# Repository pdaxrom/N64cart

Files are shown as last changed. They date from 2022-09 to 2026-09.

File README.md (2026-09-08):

# N64cart - N64 flash cartridge

* [Intro](#intro)
* [Concept](#concept)
  * [Project files](#project-files)
  * [Features](#features)
  * [Memory mapping](#memory-mapping)
* [PCB](#pcb)
  * [Order notes](#order-notes)
  * [Assembly notes](#assembly-notes)
* [Build firmware](#build-firmware)
* [Build ROM Manager](#build-rom-manager)
* [Cartridge utility](#cartridge-utility)
  * [Build](#build)
  * [How to use](#how-to-use)
  * [Remote access to the cartridge](#remote-access-to-the-cartridge)
* [ROMFS Manager](#romfs-manager)
* [Total cartridge cost (32 MB version)](#total-cartridge-cost-32-mb-version)
* [Photos of version 2](#photos-of-version-2)
* [Bill of materials for version 3](#bill-of-materials-for-version-3)
* [Photos of version 3](#photos-of-version-3)
* [Remote access from an SGI Indy](#remote-access-from-an-sgi-indy)

## Intro

N64cart is an inexpensive N64 flash cartridge you can build at home. The hardware and firmware started as a fork of Konrad Beckmann's [PicoCart64](https://github.com/kbeckmann/PicoCart64), which uses a Raspberry Pi Pico as a memory controller.

The N64 cartridge connector footprint for Eagle CAD comes from [SummerCart64](https://github.com/Polprzewodnikowy/SummerCollection).

The N64 ROM boot code is derived from [N64FlashcartMenu](https://github.com/Polprzewodnikowy/N64FlashcartMenu) and [N64 DreamOS ROM](https://github.com/khill25/Dreamdrive64/tree/main/sw/n64).

## Concept

To keep the cartridge simple and inexpensive, I used one SPI flash chip and one RP2040. Konrad's design used multiplexed PSRAM chips and two RP2040s. Flash chips rated for more than 100,000 erase/program cycles should last for many years of home use.

The RP2040's XIP interface directly addresses up to 16 MB of flash. The early design used the Extended Address (EA) register to switch between 16 MB banks on larger chips. This was slow: each bank switch required disabling XIP, switching to SPI mode to update the register, and then re-enabling XIP. N64cart now uses QSPI with 32-bit addressing, without XIP, to avoid bank switching.

The [romfs](fw/romfs) filesystem maps the sectors of stored files into a contiguous address space that the N64 accesses through the PI bus. Maximum flash capacity depends on the board version: 64 MB for version 2 with a SOIC-8 or 8 × 6 mm WSON-8 package, and 128 MB for version 3 with a SOIC-16 package.

### Project files

#### Cartridge board version 2 (SOIC-8 / WSON-8, 8 × 6 mm; 64 MB maximum)

[Schematic (PDF)](hw/n64cart-v2-soic-8.pdf)

[Schematic (Eagle CAD)](hw/n64cart-v2-soic-8.sch)

[PCB (Eagle CAD)](hw/n64cart-v2-soic-8.brd)

[Gerber files](hw/n64cart-v2-soic-8_2024-08-11.zip)

#### Cartridge board version 3 (SOIC-16; 128 MB maximum)

[Schematic (PDF)](hw/n64cart-v3-soic-16.pdf)

[Schematic (Eagle CAD)](hw/n64cart-v3-soic-16.sch)

[PCB (Eagle CAD)](hw/n64cart-v3-soic-16.brd)

[Gerber files](hw/n64cart-v3-soic-16_2024-08-11.zip)

### Features

- One LED controlled by the N64, with WS2812 RGB support on PCB version 3 (not available on PicoCart64-lite)
- A UART port accessible from the N64 (not available on PicoCart64-lite)
- USB passthrough to the N64
- Emulation of 4/16 Kbit EEPROM
- Emulation of 256 Kbit / 1 Mbit SRAM
- Emulation of 1 Mbit FlashRAM (29L1100)
- A USB utility for accessing files on the cartridge's flash chip

### Memory mapping

#### Registers

Register|Address|Mode
--------|-------|----
UART_CTRL|0x1fd01000|R-
UART_RXTX|0x1fd01004|RW
LED_CTRL|0x1fd01008|-W
SYS_CTRL|0x1fd0100c|RW
SSI_SR|0x1fd01010|RW
SSI_DR0|0x1fd01014|RW
FW_SIZE|0x1fd01018|R-

#### UART_CTRL bits

Function|Bit mask|Mode
--------|--------|----
UART_RX_AVAIL|0x01|R-
UART_TX_FREE|0x02|R-

#### UART_RXTX bits

Function|Bit mask|Mode
--------|--------|----
DATA|0xFF|RW

#### LED control bits

Function|Bit mask|Mode|Note
--------|--------|----|---
LED_ONOFF|0x01|-W|PCB v2 or PCB v3 without WS2812
LED_RGB|0x00ffffff|-W|PCB v3 only

#### SYS_CTRL bits

Function|Bit mask|Mode
--------|--------|----
EEPROM_16KBIT|0x1000|RW
FRAM_MODE|0x200|RW
SRAM_UNLOCK|0x100|RW
FLASH_MODE_QUAD|0x10|RW
FLASH_CS_HIGH|0x01|RW

#### SSI_SR bits

Function|Bit mask|Mode
--------|--------|----
SSI_SR_TFNF_BITS|0x01|R-
SSI_SR_RFNE_BITS|0x02|R-

#### SSI_DR0 bits

Function|Bit mask|Mode
--------|--------|----
DATA|0xff|RW

## PCB

### Order notes

Use a PCB thickness of 1.2 mm.

A stencil makes it easier to apply solder paste, but adds to the order cost.

### Assembly notes

After soldering the processor and flash chip, thoroughly remove flux residue from the board. Residue can cause unstable memory operation or prevent the cartridge from working.

#### PCB version 2

Populate either D2 or Q1, but not both.

Leave R1 and R6 unpopulated.

#### PCB version 3

If LED3 is populated, leave R1 and D2 unpopulated.

## Build firmware

Install the Pico SDK before building the firmware.

The default configuration is `BOARD=v3` and `REGION=ntsc`. Pass one of these options to CMake to select a different board:

- `-DBOARD=v2`: cartridge version 2 with 32/64 MB flash.
- `-DBOARD=pico`: a generic Pico cartridge with up to 16 MB of flash, without the `SI_DAT`, `SI_CLK`, `NMI`, and `INT` signals.
- `-DBOARD=pico-lite`: a PicoCart64-lite cartridge with up to 16 MB of flash, with the `SI_DAT`, `SI_CLK`, `NMI`, and `INT` signals.

Select the firmware region according to the console:

| Console | CMake option | ROM Manager video mode |
|---|---|---|
| NTSC | `-DREGION=ntsc` (default) | NTSC |
| PAL | `-DREGION=pal` | PAL |
| PAL-M / MPAL (Brazil) | `-DREGION=ntsc` (default) | MPAL |

`REGION` selects the cartridge's CIC security protocol. PAL-M consoles use the same protocol as NTSC consoles, so choose the NTSC firmware build for PAL-M too. ROM Manager gets the console's TV type from libdragon and selects the video mode automatically. No separate PAL-M build is needed, though it still needs testing on a real PAL-M console.

From the repository root, build the default configuration:

```sh
cd fw
mkdir -p build
cd build
cmake ..
make -j
```

For example, use `cmake .. -DBOARD=v2 -DREGION=pal` to build for a version 2 cartridge and a PAL console.

Hold the cartridge's bootloader button while connecting it via USB, then copy `fw/build/n64cart.uf2` to the `RPI-RP2` drive.

## Build ROM Manager

Install an N64 toolchain with [libdragon](https://github.com/DragonMinded/libdragon) built from the `opengl` branch.

Pass `BOARD=pico` to `make` for a generic Pico cartridge, or `BOARD=pico-lite` for a PicoCart64-lite cartridge. Both configurations support flash chips of up to 16 MB. No `REGION` option is needed: video mode selection is automatic for NTSC, PAL, and PAL-M consoles.

From the repository root:

```sh
cd rom
make
```

## Cartridge utility

The utility formats cartridge memory and reads and writes files. Use it to upload ROMs or change the background image.

### Build

For Linux and macOS, install the libusb development files. From the repository root:

```sh
cd utils
make
```

To build for Windows, install the MinGW toolchain. From the repository root:

```sh
cd utils
make SYSTEM=Windows
```

### How to use

Run the following commands from the `utils` directory. Before using a new cartridge, format it and upload ROM Manager:

```sh
./usb-romfs format
./usb-romfs push ../rom/n64cart-manager.z64
```

Upload a ROM, for example:

```sh
./usb-romfs push game.z64
```

To change the background image:

```sh
./usb-romfs push picture.jpg background.jpg
```

Available commands (angle brackets indicate placeholders; square brackets indicate optional arguments):

```text
./usb-romfs help
./usb-romfs bootloader
./usb-romfs reboot
./usb-romfs format
./usb-romfs list [-h] [path]
./usb-romfs delete <remote path>
./usb-romfs mkdir <remote path>
./usb-romfs rmdir <remote path>
./usb-romfs rename <source> <destination> [--create-dirs]
./usb-romfs push [--fix-rom] [--fix-pi-bus-speed[=12..FF]] <local filename> [<remote path>]
./usb-romfs pull <remote path> [<local filename>]
./usb-romfs free
```

### Remote access to the cartridge

If your computer cannot connect to the cartridge directly, you can access it through a USB-connected proxy computer. This is useful for older systems without USB, such as an SGI Indy. Build the remote-access utilities from the `utils` directory:

```sh
make remote
```

If the client and proxy use different architectures or operating systems, cross-compile `remote-romfs` for the client by specifying the compiler:

```sh
make CC="mips-sgi-irix6o32-gcc" remote-romfs
```

Copy `remote-romfs` to the client. On the proxy computer, connect the cartridge via USB and start the proxy:

```sh
./proxy-romfs
```

On the client, `remote-romfs` takes the same commands as `usb-romfs`. Add the proxy's IP address before the command:

```text
./remote-romfs <proxy IP address> <command ...>
```

[Photos of remote access from an SGI Indy](#remote-access-from-an-sgi-indy)

## ROMFS Manager

[ROMFS Manager](utils/romfs-gui) is a desktop application built with Qt. You can use it to browse, upload, and download files on N64cart over USB or through a remote proxy.

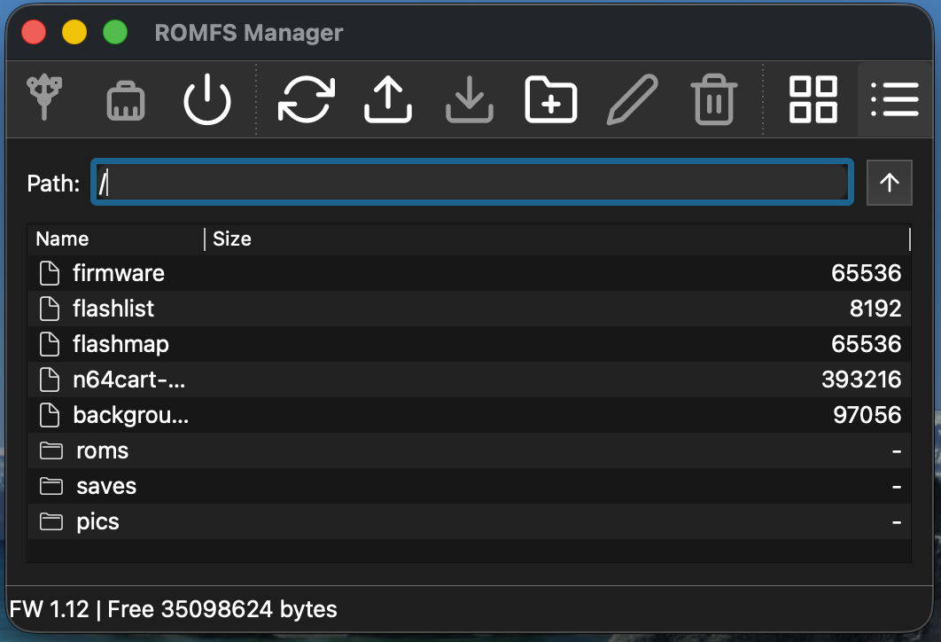
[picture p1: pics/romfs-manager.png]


## Total cartridge cost (32 MB version)

The following is an example cost breakdown for the 32 MB version. Shipping can
cost more than the components when ordering only one or two of each item.
Larger orders may qualify for free shipping.

Seller|Delivery cost|Components
------|-------------|---
[Chicago Electronic Distributors](https://chicagodist.com/)|$6-$11|RP2040
[Arrow](https://www.arrow.com/)|Free for orders > $50|SPI flash, resistors, capacitors, etc.
[JLCPCB](https://jlcpcb.com/)|$22.40|PCB

In this example, five PCBs cost $2 for the first PCB design in an order, or $4 for each additional design.

The most expensive components:

Component|Quantity|Price
---------|---|-----
RP2040|1|$1
W25Q256JVEIQ|1|$4.24
ABLS-12.000MHZ-B4-T|1|$0.26
UJ2-MIBH-G-SMT-TR|1|$0.45
LDI1117-3.3U|1|$0.34
BAT60AE6327HTSA1|2|$0.93

The remaining components (LEDs, resistors, and capacitors) came from existing stock and cost less than $1 in total.

The estimated total cost of the PCB and components is approximately $9, excluding shipping.

## Photos of version 2

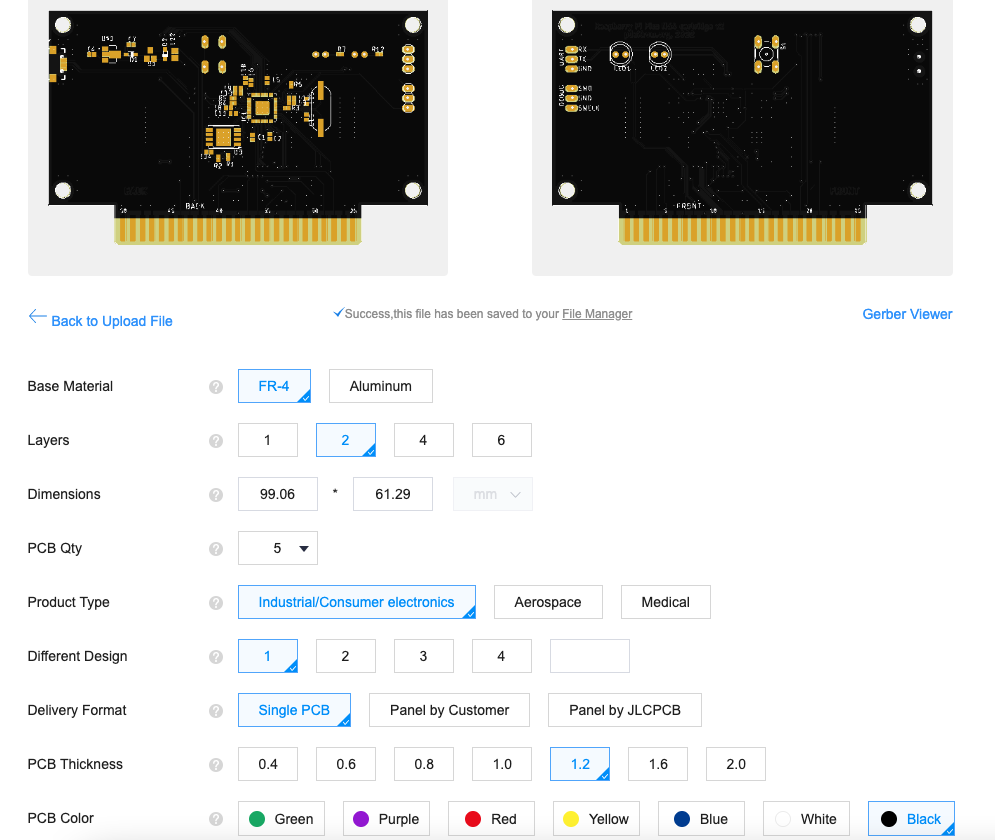
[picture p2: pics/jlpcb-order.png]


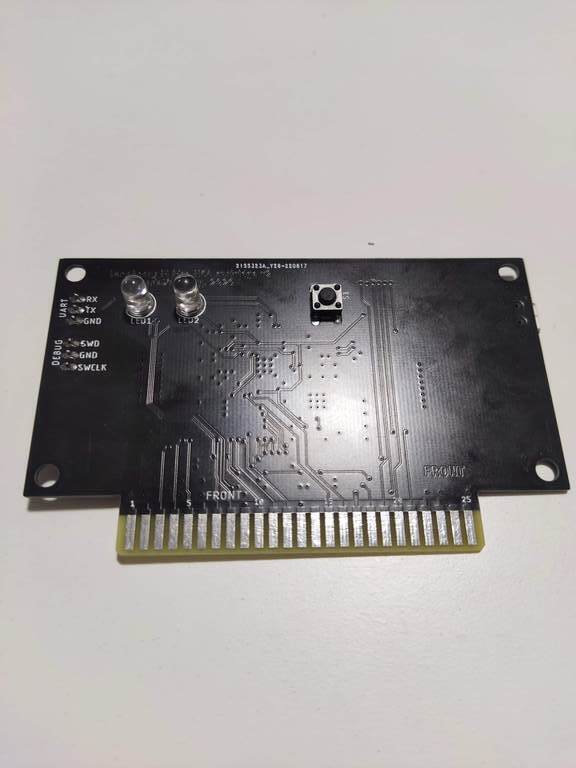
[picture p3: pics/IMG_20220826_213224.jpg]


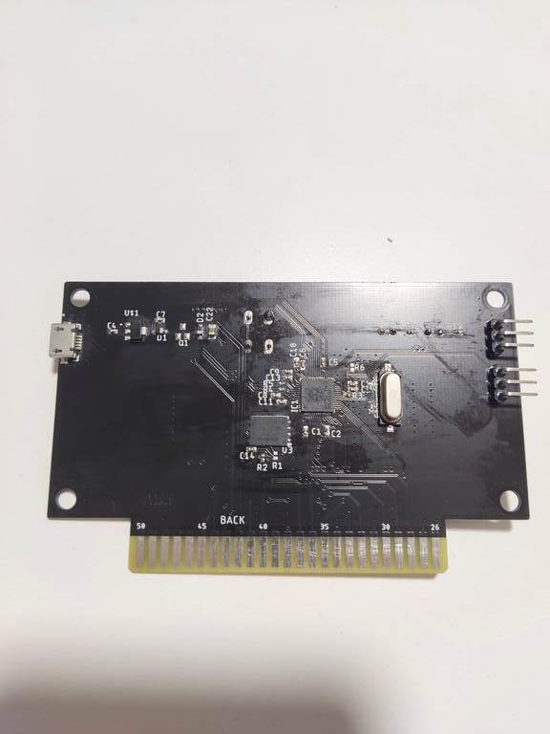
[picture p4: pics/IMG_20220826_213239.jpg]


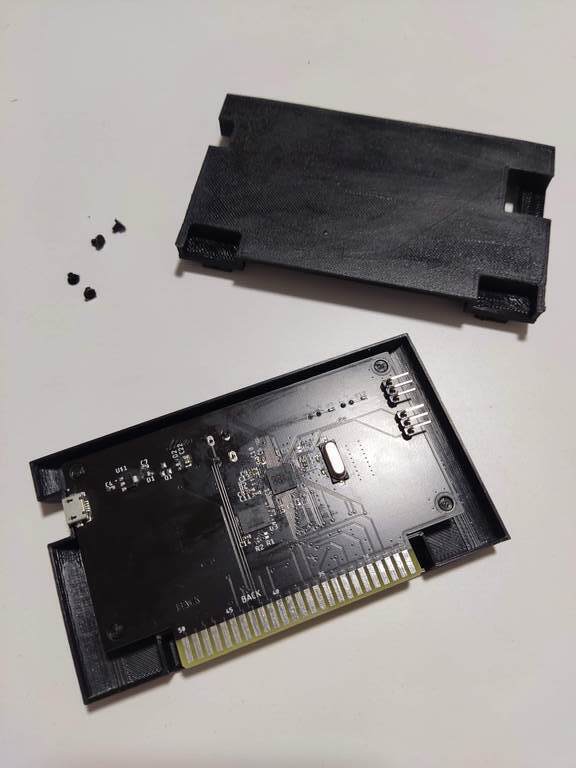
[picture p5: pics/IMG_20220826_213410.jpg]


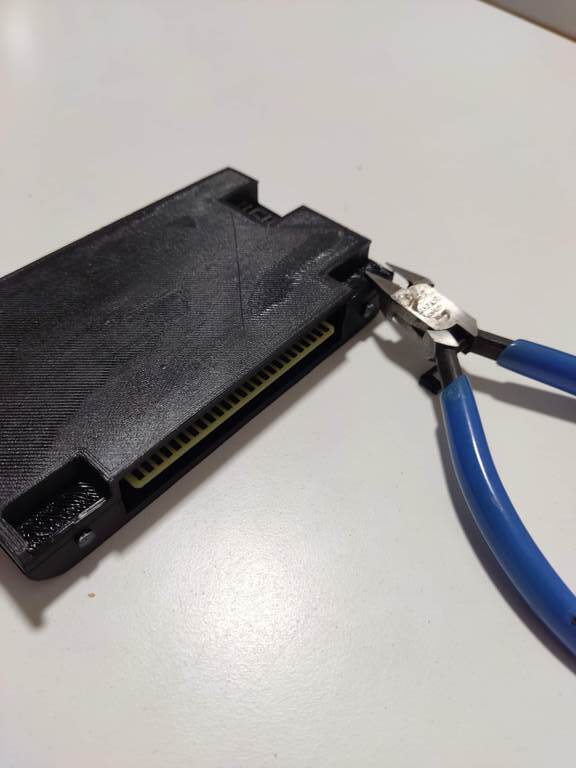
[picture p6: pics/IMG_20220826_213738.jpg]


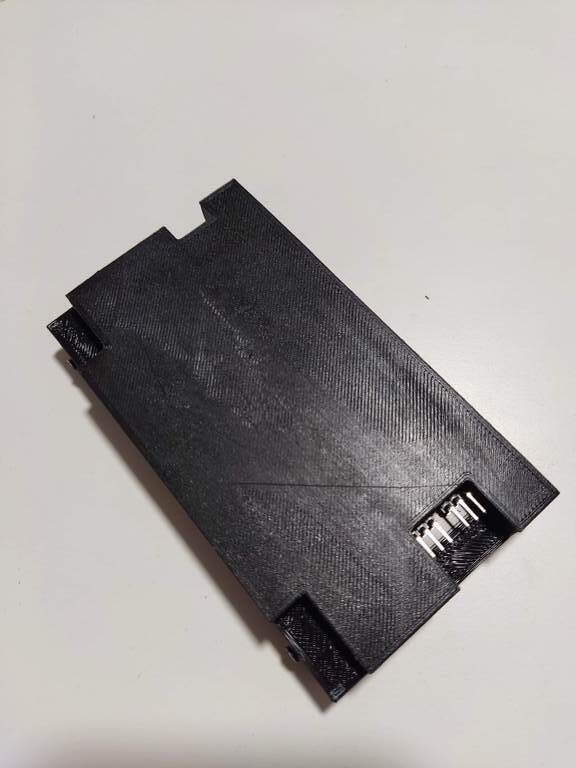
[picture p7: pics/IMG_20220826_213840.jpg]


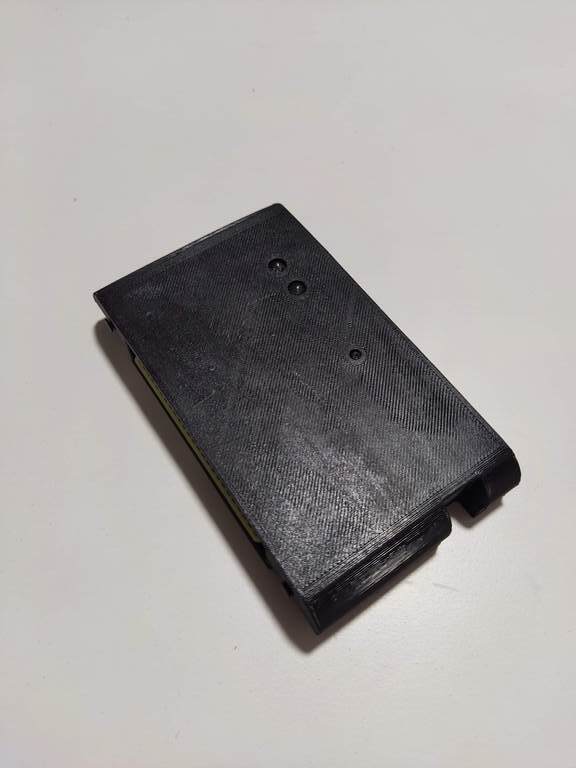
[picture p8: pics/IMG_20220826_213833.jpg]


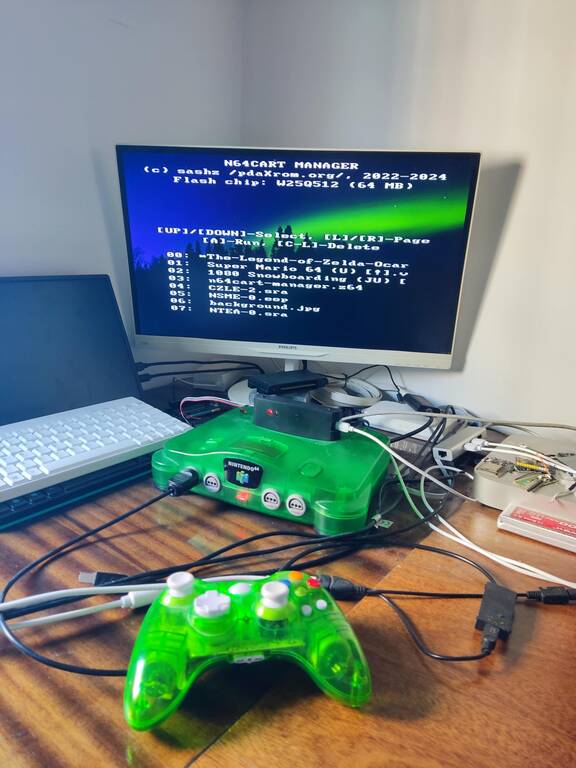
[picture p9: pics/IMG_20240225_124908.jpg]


## Bill of materials for version 3

Part|Value|Device|Package
----|-----|------|-------
C1|100n|C-EUC0402|C0402
C2|100n|C-EUC0402|C0402
C3|100n|C-EUC0402|C0402
C4|100n|C-EUC0603|C0603
C5|100n|C-EUC0402|C0402
C6|100n|C-EUC0402|C0402
C7|100n|C-EUC0603|C0603
C8|100n|C-EUC0402|C0402
C9|100n|C-EUC0402|C0402
C10|1uF|C-EUC0402|C0402
C11|100n|C-EUC0402|C0402
C12|100n|C-EUC0402|C0402
C13|1uF|C-EUC0402|C0402
C14|100n|C-EUC0402|C0402
C15|27pF|C-EUC0402|C0402
C16|27pF|C-EUC0402|C0402
C22|10u|C-EUC0805|C0805
D1|SL02-GS08|SL02-GS08|SOD-123
D2|GREEN|LED0603|0603
D3|RED|LED0603|0603
IC1|RP2040-QFN56|RP2040-QFN56|QFN-56
LED3|XL-5050RGBC-WS2812B|XL-5050RGBC-WS2812B|XL5050RGBCWS2812B
Q1|BSS84|BSS84|SOT23
R1|1K|R-EU_R0603|R0603
R2|1K|R-EU_R0402|R0402
R3|1K|R-EU_R0402|R0402
R4|27|R-EU_R0402|R0402
R5|27|R-EU_R0402|R0402
R12|1K|R-EU_R0603|R0603
S1||10-XX|B3F-10XX
U$1|LDI1117-3.3U|LDI1117-3.3U|LDI1117-3.3U
U2||USB|USB-MICRO-SMD
U4|MX66L1G45GMI-08G|MX66L1G45GMI-08G|SOP_16
XTAL1|ABLS-12.000MHZ-B4-T|ABLS-12.000MHZ-B4-T|XTAL_ABLS_ABR

## Photos of version 3

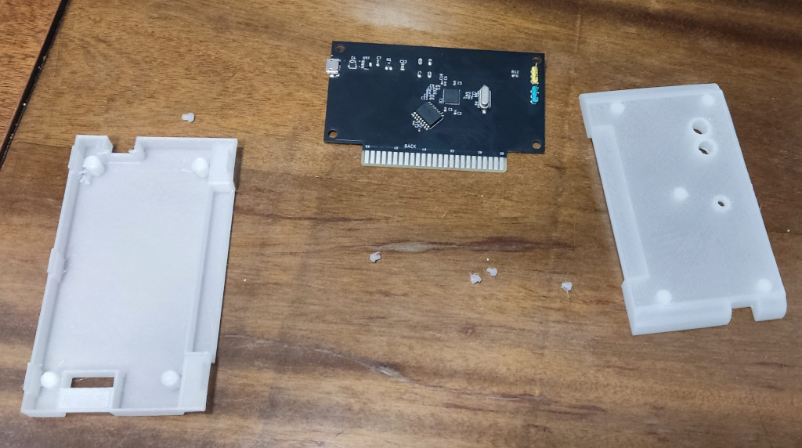
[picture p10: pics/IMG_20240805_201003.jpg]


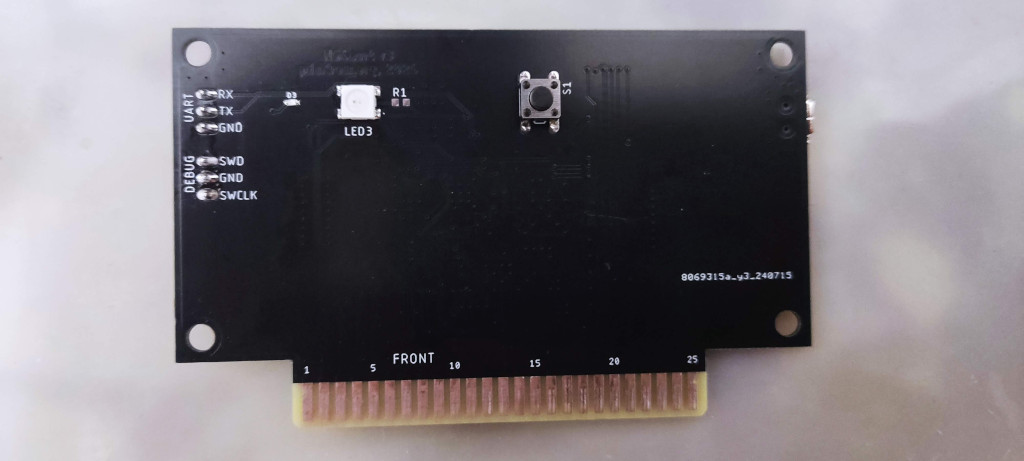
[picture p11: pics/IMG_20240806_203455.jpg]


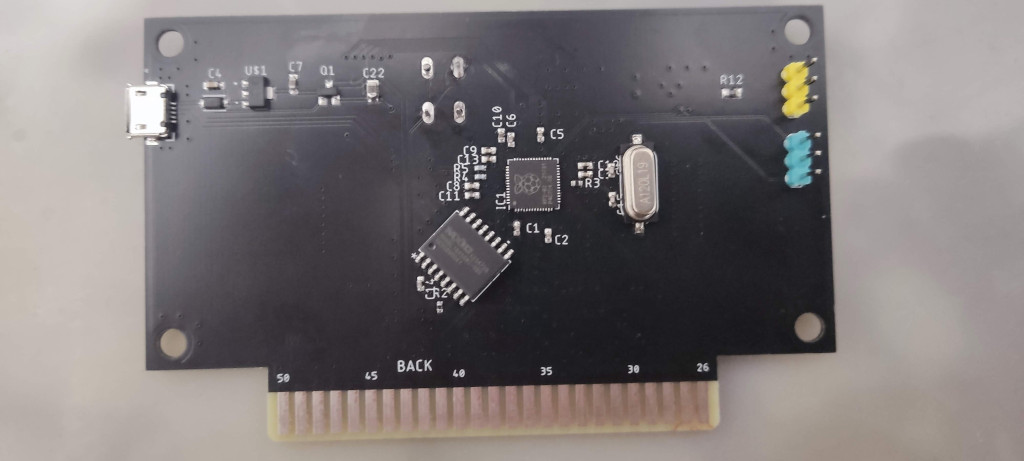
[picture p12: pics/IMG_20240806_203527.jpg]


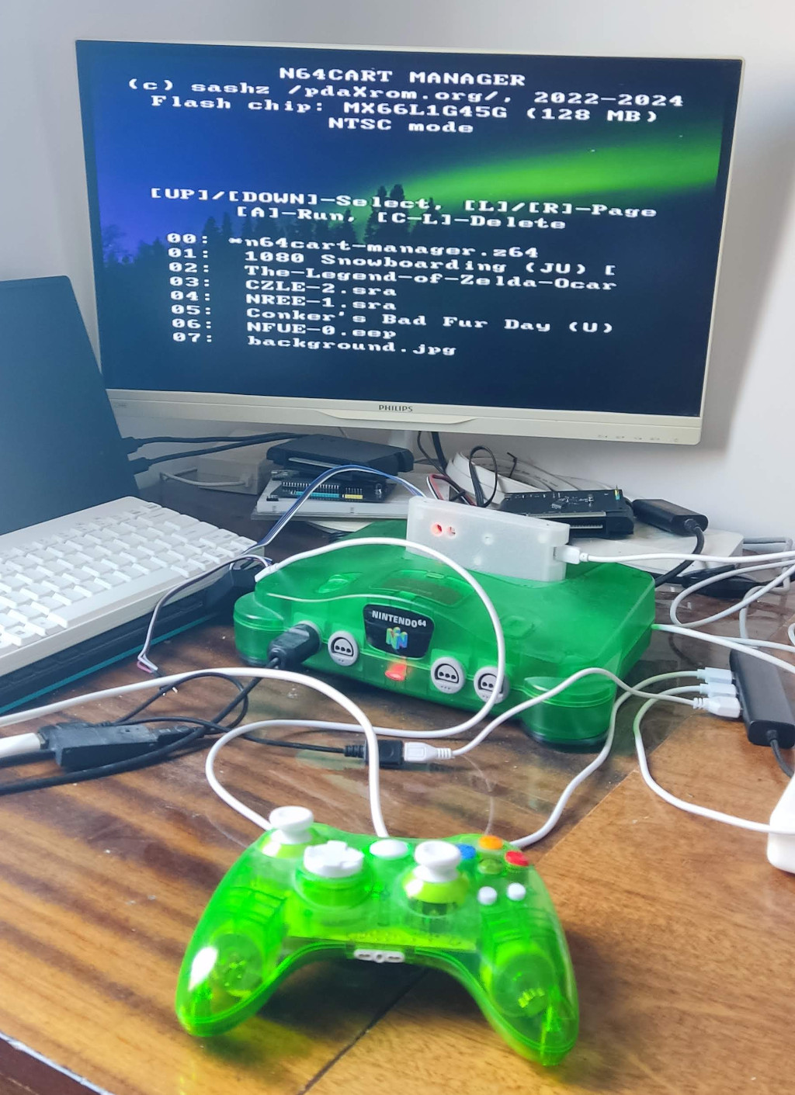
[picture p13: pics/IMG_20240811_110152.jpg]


## Remote access from an SGI Indy

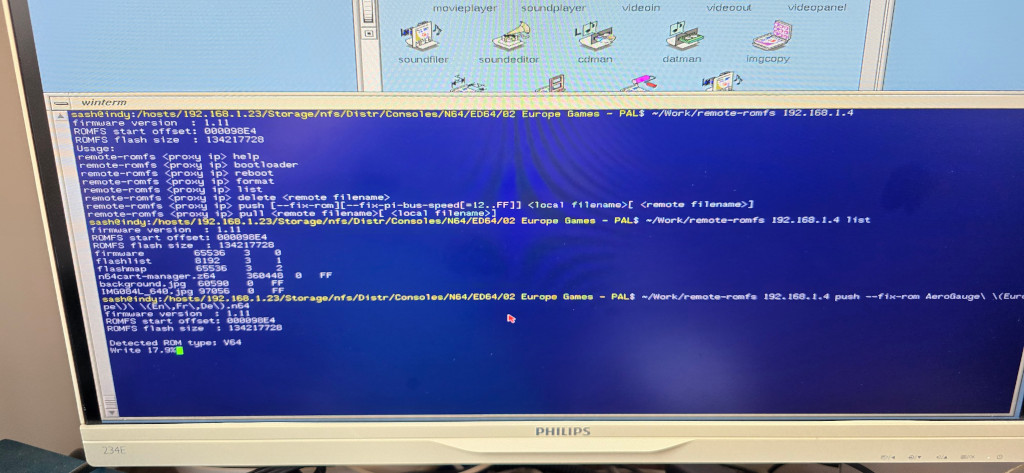
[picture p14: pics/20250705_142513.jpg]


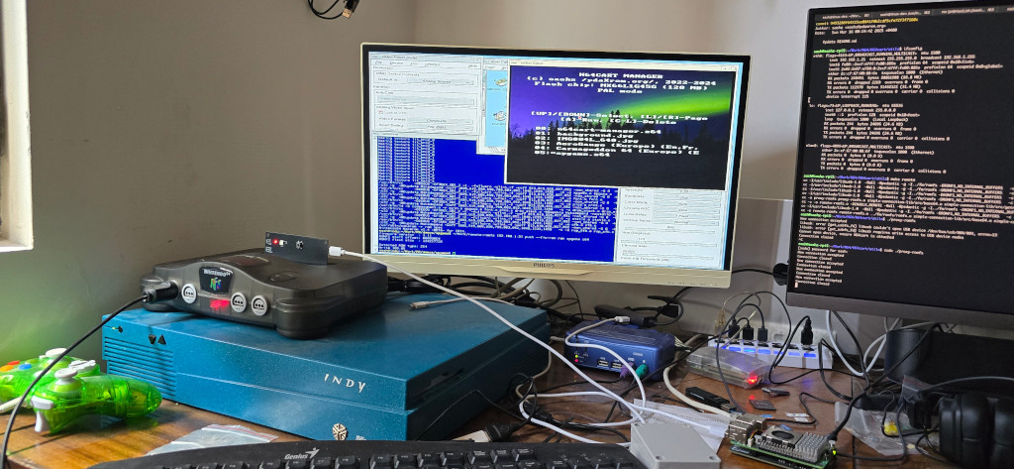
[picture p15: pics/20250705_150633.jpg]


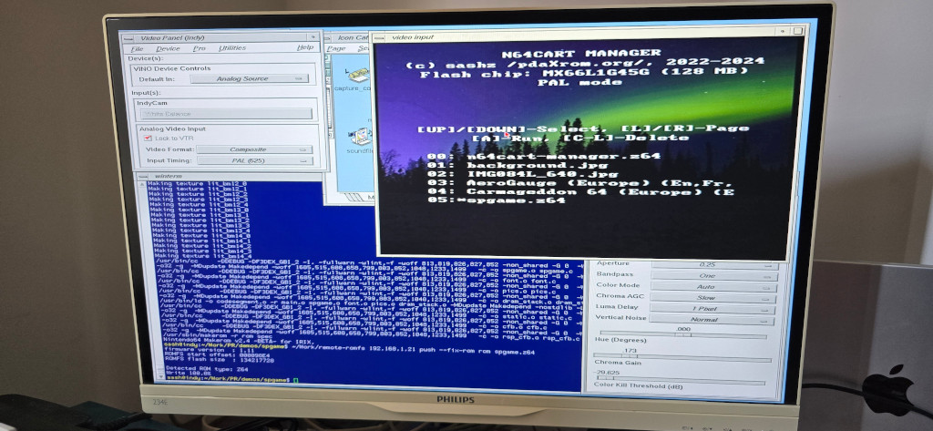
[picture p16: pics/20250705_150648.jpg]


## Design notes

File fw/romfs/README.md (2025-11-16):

# ROMFS API Overview

The ROMFS layer provides a lightweight flash-backed filesystem for the N64 cart firmware, exposing a C API that maps files and pseudo-directories onto the SPI flash. This README summarises the available calls and shows how to integrate them into firmware or host tools.

- [Core Concepts](#core-concepts)
- [Initialization](#initialization)
- [Filesystem Queries](#filesystem-queries)
- [Directory Navigation](#directory-navigation)
- [File Operations](#file-operations)
- [Flash Access Primitives](#flash-access-primitives)
- [Error Handling](#error-handling)
- [Example: Creating and Reading a File](#example-creating-and-reading-a-file)
- [Example: Recursively Listing the ROMFS Tree](#example-recursively-listing-the-romfs-tree)

## Core Concepts

ROMFS stores a flat table of `romfs_entry` records that describe files and pseudo-directories. Each entry contains:

| Field | Purpose |
|---|---|
| `name`, `attr` | ASCII name (max 53 chars) and packed mode/type bits |
| `start`, `size` | First sector in the flash map chain and file size (bytes) |

Entries can represent either files or pseudo-directories. Each directory receives an ID (`attr.names.current`) that children reference via `attr.names.parent`, allowing the API to efficiently walk or filter the flat entry table without nested structures. The ROMFS core keeps a lookup table of directory IDs so obtaining a `romfs_dir` handle is O(1), and helpers such as `romfs_dir_open_path` or `romfs_create_path` split incoming paths on `/`, create intermediate directories if requested, and reject `.`/`..` segments to keep the tree well-defined. Callers that prefer a flat namespace can keep passing bare filenames (the root directory is implied), while directory-aware code can scope operations using `romfs_dir` handles or path-based helpers.

Every entry is backed by a 4 KiB sector map (`flash_map_int`) and a list block (`flash_list_int`). The API reads these blocks into RAM and writes them back when changes occur.

## Initialization

```c
#include "romfs.h"

uint32_t map_size, list_size;
romfs_get_buffers_sizes(flash_bytes, &map_size, &list_size);

uint16_t *flash_map = malloc(map_size);
uint8_t  *flash_list = malloc(list_size);

if (!romfs_start(flash_base_offset, flash_bytes, flash_map, flash_list)) {
    // handle error
}
```

`romfs_start` must run before any other call. It loads the list/map into RAM and rebuilds internal directory indices.

## Filesystem Queries

- `uint32_t romfs_free(void);` - returns available bytes.
- `uint32_t romfs_list(romfs_file *entry, bool first);` - iterates over all entries (deprecated for directory-aware apps; use `romfs_list_dir` instead).
- `const char *romfs_strerror(uint32_t err);` - converts ROMFS error codes into strings.

The `romfs_file` struct acts both as an iterator and an open file handle. Fields of interest:

| Field | Meaning |
|---|---|
| `entry` | Snapshot of `romfs_entry` data (name, size, attributes) |
| `nentry` | Index in the entry list |
| `err` | Last operation result (`ROMFS_NOERR`, `ROMFS_ERR_*`) |

## Directory Navigation

ROMFS supports up to 16 pseudo-directories using the `romfs_dir` handle:

```c
romfs_dir root, subdir;
romfs_dir_root(&root);

if (romfs_dir_open(&root, "games", &subdir) == ROMFS_NOERR) {
    // `subdir` now refers to /games
}

// Create nested directories, allocating IDs on demand
romfs_dir saves;
romfs_dir_create(&root, "saves", &saves);
```

Directory-aware listing is performed with `romfs_list_dir`:

```c
romfs_file entry = {0};
if (romfs_list_dir(&entry, true, &subdir, true) == ROMFS_NOERR) {
    do {
        bool is_dir = entry.entry.attr.names.type == ROMFS_TYPE_DIR;
        printf("%s%s\n", entry.entry.name, is_dir ? "/" : "");
    } while (romfs_list_dir(&entry, false, &subdir, true) == ROMFS_NOERR);
}
```

Helper routines:

| Function | Description |
|---|---|
| `romfs_dir_root` | Returns the root directory handle (`/`) |
| `romfs_dir_open` | Resolves a single child (no `/`) beneath a parent |
| `romfs_dir_open_path` | Walks a slash-separated path (e.g. `games/pal`) |
| `romfs_dir_create` | Creates a new directory entry (fails if it exists) |
| `romfs_dir_remove` | Deletes an empty directory by handle |
| `romfs_mkdir_path` | Convenience for building paths (`create_parents` makes intermediate directories) |
| `romfs_rmdir_path` | Removes an empty directory by path |

## File Operations

Open/create via handle-based functions:

```c
uint8_t io_buffer[ROMFS_FLASH_SECTOR];

romfs_file fh;
if (romfs_create_path("games/mario.n64", &fh,
        ROMFS_MODE_READWRITE, ROMFS_TYPE_MISC,
        io_buffer, true) == ROMFS_NOERR) {
    // Use romfs_write_file to append data (partial blocks go through io_buffer)
}
```

- `romfs_create_file` / `romfs_create_file_in_dir` / `romfs_create_path`
- `romfs_open_file` / `romfs_open_file_in_dir` / `romfs_open_path`
- `romfs_open_append` / `romfs_open_append_in_dir` / `romfs_open_append_path`
- `romfs_rename` / `romfs_rename_in_dir` / `romfs_rename_path`
- `romfs_delete` / `romfs_delete_in_dir` / `romfs_delete_path`
- `romfs_seek_file` / `romfs_tell_file`

Append handles behave like `fopen("a")`: the file is created if missing, the write cursor starts at the current end, and partially filled sectors are rewritten in-place before new sectors are chained on.

Rename helpers let you move files or directories between parents while updating their names in one shot. When renaming directories, the API prevents moving a folder into its own subtree.

Once open:

| Function | Behaviour |
|---|---|
| `romfs_write_file(const void *buffer, uint32_t size, romfs_file *file)` | Writes up to 4 KiB at a time, buffering partial blocks |
| `romfs_read_file(void *buffer, uint32_t size, romfs_file *file)` | Reads up to 4 KiB; sets `file->err` to `ROMFS_ERR_EOF` on completion |
| `romfs_read_map_table(uint16_t *map, uint32_t count, romfs_file *file)` | Retrieves the chain of sectors used by a file |
| `romfs_close_file(romfs_file *file)` | Flushes any pending write buffers |
| `romfs_seek_file(romfs_file *file, int32_t offset, int whence)` | Repositions a read handle relative to `SEEK_SET`, `SEEK_CUR`, or `SEEK_END`; bounds-checks against the current file size |
| `romfs_tell_file(romfs_file *file, uint32_t *position)` | Reports the logical cursor for the next read (`read_offset` for read handles, flushed bytes for writers) |

Files opened for write require a sector-sized scratch buffer (`io_buffer`). When writes cannot be satisfied (disk full, buffer missing, etc.), the API automatically unlinks any new sectors to leave ROMFS consistent.

## Flash Access Primitives

ROMFS never touches the hardware directly. Instead, the platform must provide blocking implementations of the three flash hooks declared in `romfs.h`. All offsets are absolute byte addresses within the SPI flash (the same values you pass to `romfs_start`), and each function returns `true` on success to keep internal state machines moving.

| Function | Purpose |
|---|---|
| `bool romfs_flash_sector_read(uint32_t offset, uint8_t *buffer, uint32_t need)` | Copies `need` bytes starting at `offset` into `buffer`. Reads may span less than a full sector to satisfy tail fragments, but the ROMFS core only requests ranges contained inside a single 4 KiB sector. |
| `bool romfs_flash_sector_write(uint32_t offset, uint8_t *buffer)` | Programs one `ROMFS_FLASH_SECTOR`-sized block at `offset`. The buffer must already contain the fully prepared sector image; ROMFS handles read/modify cycles in RAM before calling into this hook. |
| `bool romfs_flash_sector_erase(uint32_t offset)` | Erases a single 4 KiB sector aligned to `ROMFS_FLASH_SECTOR`. Implementations must block until the device reports the sector is blank (typically all `0xff`). |

The ROMFS formatter and metadata loader call these hooks during `romfs_start` and `romfs_format`, and file I/O uses them whenever sectors roll over. Hardware ports usually wrap lower-level flash drivers or USB bridge commands:

```c
bool romfs_flash_sector_write(uint32_t offset, uint8_t *buffer)
{
    flash_wait_ready();
    flash_cs_assert();
    flash_program_sector(offset, buffer, ROMFS_FLASH_SECTOR);
    flash_cs_release();
    return flash_check_status() == FLASH_OK;
}
```

Returning `false` from any primitive propagates `ROMFS_ERR_OPERATION` to the caller, keeping higher layers aware of transport failures or protection faults.

## Error Handling

Common error codes:

| Code | Meaning |
|---|---|
| `ROMFS_NOERR` | Success |
| `ROMFS_ERR_NO_IO_BUFFER` | Missing sector buffer for read/write |
| `ROMFS_ERR_NO_ENTRY` | Entry not found |
| `ROMFS_ERR_NO_FREE_ENTRIES` | Entry table exhausted |
| `ROMFS_ERR_NO_SPACE` | Flash has no free sectors |
| `ROMFS_ERR_FILE_EXISTS` | Creating a file that already exists |
| `ROMFS_ERR_BUFFER_TOO_SMALL` | Provided map/table buffers are too small |
| `ROMFS_ERR_DIR_LIMIT` | Out of directory IDs (max 16) |
| `ROMFS_ERR_DIR_NOT_EMPTY` | Attempted to remove a non-empty directory |

Inspect `romfs_file.err` or return values after every call. Convert to text with `romfs_strerror`.

## Example: Creating and Reading a File

```c
uint8_t io_buffer[ROMFS_FLASH_SECTOR];
romfs_file fh;

// Create nested directories and file
romfs_mkdir_path("saves/profile", true, NULL);
if (romfs_create_path("saves/profile/slot1.bin",
        &fh, ROMFS_MODE_READWRITE, ROMFS_TYPE_MISC,
        io_buffer, false) == ROMFS_NOERR) {
    const char payload[] = "hello romfs";
    romfs_write_file(payload, sizeof(payload), &fh);
    romfs_close_file(&fh);
}

// Later: open for reading
if (romfs_open_path("saves/profile/slot1.bin", &fh, io_buffer) == ROMFS_NOERR) {
    char buffer[32];
    if (romfs_read_file(buffer, sizeof(buffer), &fh) > 0 &&
        fh.err == ROMFS_ERR_EOF) {
        // buffer contains the payload
    }
}
```

## Example: Recursively Listing the ROMFS Tree

```c
static void list_dir(const romfs_dir *dir, const char *prefix)
{
    romfs_file entry = {0};
    if (romfs_list_dir(&entry, true, dir, true) != ROMFS_NOERR) {
        return;
    }

    do {
        bool is_dir = entry.entry.attr.names.type == ROMFS_TYPE_DIR;
        printf("%s%s%s\n", prefix, entry.entry.name, is_dir ? "/" : "");

        if (is_dir) {
            romfs_dir child;
            if (romfs_dir_open(dir, entry.entry.name, &child) == ROMFS_NOERR) {
                char next[256];
                snprintf(next, sizeof(next), "%s%s/", prefix, entry.entry.name);
                list_dir(&child, next);
            }
        }
    } while (romfs_list_dir(&entry, false, dir, true) == ROMFS_NOERR);
}

romfs_dir root;
romfs_dir_root(&root);
list_dir(&root, "/");
```

This produces a tree-style listing similar to:

```
/games/
/games/mario.n64
/saves/
/saves/profile/
/saves/profile/slot1.bin
```

---

For more examples, see:

- `utils/usb-romfs.c` - host utility supporting directory creation and recursive uploads
- `newlib-romfs.c` - registers `romfs:/` with newlib via `attach_filesystem`, letting firmware use `fopen`, `mkdir`, `chdir`, etc. without touching the raw API

The ROMFS layer is intentionally minimal; feel free to extend this README as new helpers or workflows are introduced. Bugs and pull requests are welcome!

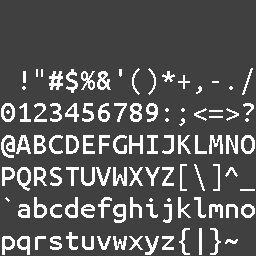
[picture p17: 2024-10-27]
rom/assets/UbuntuMono-Regular-16.png

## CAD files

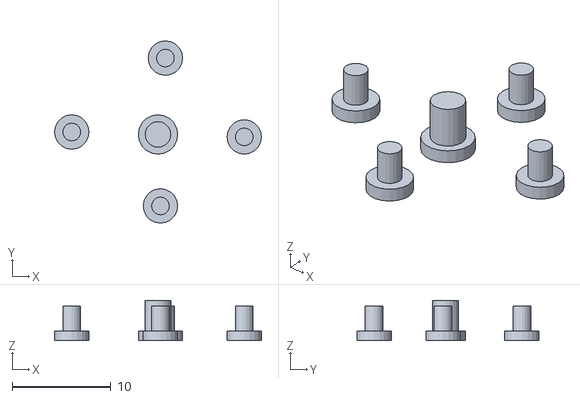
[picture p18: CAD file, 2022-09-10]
case/n64cart-misc.stl
21.0 x 18.5 x 4.10

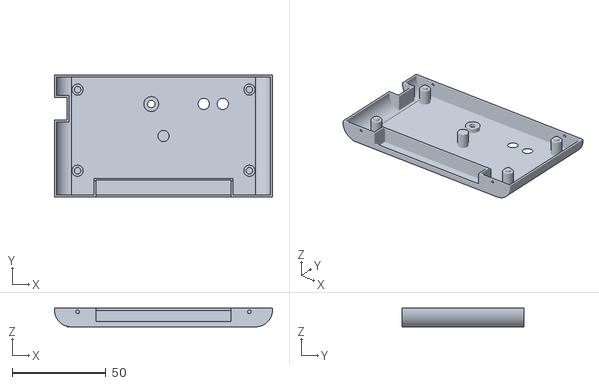
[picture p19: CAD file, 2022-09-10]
case/n64cart-front.stl
116.0 x 65.0 x 10.0

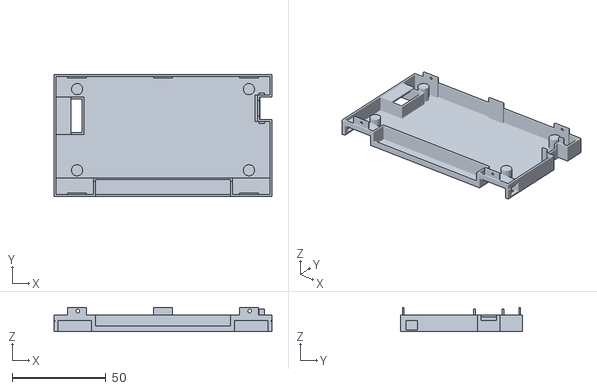
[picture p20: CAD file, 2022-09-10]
case/n64cart-back.stl
116.0 x 65.0 x 13.0

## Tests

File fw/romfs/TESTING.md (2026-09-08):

# Host ROMFS tests

Run these commands from the repository root:

```sh
make -C fw/romfs all
make -C fw/romfs check
```

The default build uses AddressSanitizer and UndefinedBehaviorSanitizer, with
sanitizer recovery disabled. Executables, objects and logs go to the ignored
`build-romfs-tests/` directory. `make check` runs the flash emulator, geometry,
chain corruption, handle ownership, I/O failures, write counts/ordering, chain cursor,
newlib bridge, platform callback/USB, and
process-level runner checks, including the full ROMFS suite. It requires
Python 3 and Bash on a POSIX host in addition to the C compiler. CLI tests use
`RLIMIT_FSIZE` to exercise real host write/close failures.

`BUILD_DIR` overrides the output directory; choose a top-level `build-*`
directory. `ROMFS_BIN` overrides the CLI executable used by `test.sh`.
Clean before changing compiler, flags or the CLI's `FLASH` setting. `make clean`
removes the named binaries, objects and dependency files, preserving logs and
scratch images. `SANITIZERS=` can disable instrumentation for a separate build.

## Reproduce a suite run

```sh
build-romfs-tests/test
build-romfs-tests/test --seed 123 --flash-mb 16
build-romfs-tests/test --help
```

The default seed is 1, and the default sizes are 16/32/64/128/256 MiB. The runner
prints the seed, per-size result, flash callback counts, and final PRNG state.
Each size starts with its own seed-derived PRNG state, so selecting one size
reproduces its part of the full run. Randomness uses explicit 32-bit arithmetic
and does not depend on the host libc's `rand()` implementation.

Exit codes for the C runner:

| Code | Meaning |
|---|---|
| 0 | Every selected suite passed; or `--help` was requested |
| 1 | At least one suite failed |
| 2 | Invalid arguments |

The size selector accepts integers from 2 through 256 MiB. The process runner
also runs standalone suites for 2/4/8 MiB. The geometry regression executable
covers 2/4/8/16/32/64/128/256 MiB. Existing randomized capacity tests accept documented
`NO_SPACE` / `NO_FREE_ENTRIES` outcomes and require successful close after ENOSPC.
The I/O and CLI tests additionally require readback of the accepted prefix and
reclamation of every sector after deletion. Remaining performance review items
have separate coverage requirements.

## Geometry and platform guards

```sh
build-romfs-tests/test_geometry
python3 fw/romfs/test_platform.py --build-dir build-romfs-tests
```

The size query does not change the active mount. Flash sizes must be nonzero,
sector-aligned and at most 256 MiB. Mounting additionally requires non-null
buffers (with the map aligned for `uint16_t`), space for metadata after the
32 KiB aligned firmware boundary, and at least one usable data sector.
Callers remain responsible for providing buffers of the queried sizes.
Rejected geometry must cause no I/O and preserve the previous mount and buffers.

Geometry tests check the existing metadata layout, exact free space, allocation
of the last usable sector, ENOSPC, GC reuse and remount/readback. A valid large
file chain is constructed directly and persisted to reach capacity quickly;
this is not a full-device payload write test. Map padding is excluded from
allocation. At 256 MiB, index `65535` stays reserved because `0xffff` remains
the free/invalid sentinel. The last physical sector is untouched by ROMFS file
allocation. The disk format and metadata sizes are unchanged.

`test_platform.py` extracts the current ARM/N64 erase/write callbacks, boundary
functions and USB command handler verbatim into generated includes under the
build directory, then compiles them with `test_platform.c` hardware substitutes.
Extraction fails if a definition cannot be identified uniquely. Tests check
that invalid offsets never reach erase/program or mode/interrupt changes;
metadata and the last physical sector remain accessible through valid raw
commands. They also check low-level failure returns, restoration of N64 mode
and interrupts, early USB rejection, the second check at write completion,
error ACK conversion, and recovery with a following valid command.

The N64 host harness models big-endian field values with explicit byte swaps;
it does not emulate MIPS execution or a USB controller. Full ARM/MIPS builds
and physical USB/PI smoke tests are separate. Core I/O error propagation and
partial-file preservation are exercised by `test_io` and the bridge/CLI tests.

## Corrupted chains

`build-romfs-tests/test_chains` arranges deterministic corrupt images, persists
them and remounts before testing. It also exercises handles opened before the
corruption, dirty write buffers, and live corruption of service links.
Coverage includes invalid start/next indices, map padding, links into service
regions, early termination, missing terminal self-links, cycles, wrong sizes,
arithmetic overflow, and mismatched buffer/chain sectors.

ROMFS validates a complete chain against its size before open/read/seek/map
export and file mutations. A normal empty file uses start `0xffff`; a nonempty
file must have exactly the required number of sectors and a final self-link.
Service files are readable only with their expected geometry and within their
own service range. Invalid chains return `ROMFS_ERR_OPERATION`. Read/write
return byte counts, including zero on rejection, with the error in `file->err`.
Rejected reads and map exports leave output buffers and positions unchanged.

Truncate validates before syncing a dirty buffer or changing the catalog/map.
GC preflights every eligible deleted file before freeing any of them, and
propagates a corrupt-chain error through catalog/sector allocation. If a corrupt
tombstone blocks GC, `romfs_free()` reports only sectors already marked free.
The tests compare the entire image, map and catalog and require zero callbacks
on these rejection paths. They verify that valid GC works after the fixture's
bad link is repaired; production code does not repair corrupt user chains.

Validation uses a bounded walk and no additional bitmap or heap allocation.
It still adds a full chain walk to read/write/seek operations, so small I/O
calls on large files cost more. A local write cursor removes repeated position
searches within an operation, as described below; validation results are not
cached across public calls. This checks each chain's structure and range,
not ownership of sectors shared by otherwise structurally valid files.

## Handle ownership and names

```sh
build-romfs-tests/test_ownership
build-romfs-tests/test_newlib
```

Successful create/open registers the descriptor at its address. The caller must
keep it alive and stationary until close, and close it on every error path before
leaving scope or freeing it. Copying a descriptor does not create another usable
handle. Reopening or listing into an active descriptor returns `ROMFS_ERR_BUSY`
without overwriting it. No heap allocation or fixed handle-count limit is added
to the core; the registry is an intrusive list. Calls still require external
serialization; this does not make the filesystem thread safe.

New files reserve a catalog slot and name before their first flush/close, so two
unflushed creates cannot claim the same slot. Multiple ordinary readers may
coexist, but a writer excludes other ordinary opens of that file. Delete and
rename reject open files with `ROMFS_ERR_BUSY`. Pending children prevent directory
removal, and open descendants prevent directory rename. File and directory names
share a namespace; invalid components are rejected before automatic parent
creation. Names must have 1–53 bytes, contain no slash, differ from `.` and `..`,
and not start with the empty/deleted markers. This does not repair old images
that already contain duplicate or invalid names.

`romfs_open_read_view` flushes a writer and opens a temporary read-only view.
The writer cannot write/flush/truncate until the view closes. Newlib uses this
for `O_RDWR`, closes the view after each read (including EOF/error), then updates
the owning writer's position. Ordinary conflicts map to `EBUSY`. Closing a file
unregisters it even if flush returns an error; flush itself retains ownership.
A closed descriptor must be reopened before further I/O. Repeated close is a
no-op. Partial-write recovery and flash callback errors are described below.

Directory IDs are released only at deletion; GC must not release an ID now owned
by another directory. Directory handles carry a runtime generation and catalog
index, preventing stale handles/cursors from accessing a replacement even when
both ID and slot are reused. Mount with valid geometry and format invalidate
previous file/non-root directory handles, including on a subsequent I/O failure;
a geometry-rejected mount preserves them.
The in-memory `romfs_file` and `romfs_dir` ABI changed, so clients must be rebuilt.
The on-flash `romfs_entry` layout, map and sentinel values are unchanged.

Ownership tests exercise reverse-order close/remount of two pending writers,
shared readers, stale copies, directory ID/slot reuse through actual catalog GC,
all reserved catalog slots, invalid names, mount invalidation and read views.
Ownership-specific failed opens/closes use invalid buffers/operations; `test_io`
injects flash failures. Rejected ownership operations compare the entire image, map and
catalog and check that no flash callback ran. Corruption tests use actual open
descriptors for live damage, closing each before opening a conflicting writer.

The newlib harness compiles the production `newlib-romfs.c` with minimal libdragon
callback declarations in `test_newlib_stubs/`; it does not copy bridge logic.
Host-only symbol renaming keeps its `rename`/`rmdir` away from host libc calls.
Tests cover alternating `O_RDWR` reads/writes/seeks across sectors, EOF, read
errors, truncate, conflicting opens, preservation of both rename endpoints,
failed-close cleanup and stale directory cursors. Full MIPS builds separately
check the real libdragon headers; no MIPS runtime is emulated here.

## Newlib open flags

The bridge creates files only with `O_CREAT`, including `O_RDONLY | O_CREAT`.
Without it, a missing file or parent returns `ENOENT`. With it, the existing
automatic parent-creation behavior is preserved. `O_CREAT | O_EXCL` rejects both
published and pending names with `EEXIST`, in all three access modes. `O_EXCL`
without `O_CREAT` is ignored. An invalid access mode or read-only `O_TRUNC`
returns `EINVAL` before any filesystem changes.

Existing writable files open through `romfs_open_write_path`, which never creates
a file or parent and starts at offset zero. The low-level `romfs_open_append*`
APIs retain their create-if-missing behavior and initial EOF position. Newlib
handles start at zero, including `O_APPEND`: append seeks to the current EOF
before every write, even after reads, seeks or truncate.

`O_TRUNC` acquires the writer and calls `romfs_truncate_file(..., 0)`, preserving
the catalog slot, name, parent and attributes. `O_APPEND | O_TRUNC` truncates
first. Write opens of read-only/system/reserved or service files return `EACCES`;
directory opens return `EISDIR`. Exclusive creation of an occupied name takes
precedence over these errors. Busy files return `EBUSY` before truncation.

The bridge tests cover 192 flag combinations across existing files, missing
files with an existing parent, and missing parents. They check sizes, contents,
offsets, access failures, slot/attribute preservation and remount readback.
Additional cases cover append after read/seek/truncate, pending exclusive
creation, busy truncation, protected entries and directories. Rejected flag,
access and ownership checks require an unchanged image/map/catalog and zero
flash callbacks. Fault injection checks the catalog sector for empty read-only
creation and both catalog/map sectors for nonempty truncation: failures return `EIO`, preserve that errno during
cleanup, and release handles. These I/O failures can leave creation/truncation
applied in RAM; synchronization and close recovery still follow the I/O contract
below, without rollback or power-loss guarantees.

## I/O errors and partial transfers

`build-romfs-tests/test_io` injects failures into mount reads, data buffer
read/erase/write (including first writes of new sectors), truncate tail I/O,
and each changed metadata sector on a 2 MiB image. Format changes both sectors;
mkdir, delete, rmdir, rename and empty-file flush/close change only the catalog.
Tests include repeated failures before a successful retry. `test_metadata`
extends this to every sector of a 256 MiB image and sparse dirty-sector sets.

Each failed flash callback returns `ROMFS_ERR_IO` through the calling operation
(or false from start/format). An erase failure prevents the corresponding write.
Dirty buffers remain dirty until erase and program both succeed. A failed load
invalidates the buffer's cached sector. Allocation reserves a sector in the RAM
map without flash I/O; its buffer is initialized to zero and filled with accepted
data. The first physical write happens at a full buffer or flush/close. Shared
sync must write every changed writer's data before publishing metadata. A failed
new-sector write retains the reservation and dirty buffer for retry; failed close
reclaims unpublished tail allocations as described below. Truncate performs tail
I/O before releasing chain links.

Read returns only successfully read fragments and advances by that count. A
failed callback may have touched its destination, so bytes beyond the returned
count are not valid. Write counts bytes accepted into the file's RAM buffer,
including a full sector whose later flush failed; inspect `file->err` even when
the return is nonzero. Successful flush/close confirms callback completion for
accepted data and metadata. ENOSPC is a short-write condition, not a reason for
close to discard the accepted file. Close reports its own synchronization result.

Capacity tests use a deterministic 32 KiB image to exercise create, append,
overwrite, gap extension and truncate at capacity, then remount/read back the
accepted data, delete the file and reuse all sectors. Zero-filled gap/truncate
extensions can remain partially applied on failure; failed gap filling returns
zero caller-data bytes and preserves the caller's requested position.

`romfs_sync()` synchronizes changed open writers before flushing the shared map
and catalog. A commit must not combine one writer's extended chain with its old
catalog size. Thus closing one file or changing a directory may also synchronize
other open writers and can report their errors. Tests remount after closing only
one of two writers and verify both entries and data. Unchanged writers with an
active read view need no synchronization and retain their ownership rules.

Failed metadata writes retain the pending state. Directory changes may already
exist in RAM when the operation returns an I/O error; call `romfs_sync()` before
remounting to retry them. This is not transaction rollback. Repeated mkdir of an
existing directory also retries synchronization. A failed mount read disables
access to the incomplete mount until another successful start; it cannot restore
old caller-owned buffers that have already been partially overwritten.

Before close, a failed data flush can be retried with the descriptor and its RAM
buffer intact. Close releases the descriptor even on error: for a valid chain it
reclaims tail allocations beyond the entry already in the RAM catalog, preserving
that entry's chain. Catalog/map writes still pending can be retried with
`romfs_sync()`. Invalid chains are never traversed for speculative cleanup.

Newlib tests verify short read/write results, positions, `EIO`/`ENOSPC`, failed
close and partial-file readback. Host CLI tests use a separately compiled 2 MiB
`romfs-small` executable for deterministic capacity tests, input/output failures,
write/close size limits and preservation of the local destination on remote-open
failure. Host CLI exit codes are 0 for success, 1 for operation/I/O failure, and 2
for invalid arguments. Only format may create a missing image; images of the wrong
size are rejected. `list`, `free`, and `pull` preserve image contents and mtime.

N64 save loading aborts ROM launch on read failure or incomplete save length;
open failures other than ENOENT also abort. Save writing checks fclose and logs
success only on successful transfer/flush/close. Its existing policy of deleting
failed save writes remains. Physical cartridge validation of these paths is still
required. The USB/remote CLI and GUI detect partial transfers and report errors.

These checks model callback failures, not power-loss atomicity or reliable driver
detection of every physical flash fault. Failed in-place erase/program can damage
existing data or metadata. Generation snapshots and data copy-on-write remain
deferred in `TODO.md`; the on-flash format is unchanged here.

## Single programming of new sectors

```sh
build-romfs-tests/test_write
build-romfs-tests/test_write --measure
```

The write harness links the same NOR emulator with renamed callbacks and wraps
them to count data and metadata requests separately. `--measure` reports counts
and verifies round-trip contents without requiring the optimized counts, so it
can also measure an older core. The ordinary run asserts one erase/program per
new data sector for sequential creation, including a partial last sector.

Measured on a 16 MiB image (numbers are erase/program pairs for file data):

| Operation | Before deferred allocation | Current |
|---|---:|---:|
| Create 1 MiB | 512 | 256 |
| Create 1 MiB + 17 bytes | 514 | 257 |
| Append 4096 bytes to a 17-byte file | 3 | 2 |
| Overwrite 17 bytes inside a two-sector file | 1 | 1 |
| Append 17 bytes to a one-sector file | 2 | 1 |

Before dirty tracking each measured operation additionally wrote three metadata
sectors. Currently creation and these appends write two (one catalog and one map
sector); overwrite changes neither. Reads remain zero for new sectors; appending
to a partial sector and partial overwrite each read the existing sector once. Repeated flushes or writes
to the same previously stored sector can still require another erase/program.
These counts are not elapsed-time measurements on a cartridge.

Further tests fill and delete a six-sector file to force GC reuse, then check
partial writes, zero-filled gaps and truncate extension. They verify both the
logical file and physical zero bytes beyond EOF. Two pending writers must reserve
different sectors without any I/O. Before each metadata erase/program the wrapper
checks that both data buffers already match flash, including after a failure in
either writer, for ordinary sync and explicit full sync. Gap/truncate retries inject erase/program failures into an old
partial sector or a new sector, retaining offsets, the accepted prefix and zeros.
Existing I/O tests cover ENOSPC and reclamation after a failed close.

## Chain cursor and traversal counts

```sh
build-romfs-tests/test_cursor
build-romfs-tests/test_cursor --measure
```

Each public write initializes a local logical/physical cursor during the full
chain validation. That same walk checks the cached I/O buffer's physical sector,
even if a preceding seek placed the write position elsewhere. Forward writes
follow the cursor instead of starting at the beginning of the file for every
sector. The cursor survives full-buffer flushes and internal zero-fill calls;
truncate extension also uses it. It occupies two uint32_t fields on the stack,
with no persistent handle fields or heap allocation.

The cursor is discarded on return, including failures. Every subsequent public
write revalidates the complete chain and obtains a fresh position. Direct edits
to the caller-owned map therefore cannot bypass the existing corruption checks.
Read/seek validation and dirty-buffer consistency checks remain in place.

`test_instrument.py` generates `build-romfs-tests/romfs-instrumented.c` from the
production source. It inserts counters at the map link loads in validation and
sector-position lookup; it requires one matching function and one matching load
for each counter and fails if the source cannot be identified. No counters or
conditional instrumentation are added to the production core. `test_cursor`
links this generated core with the same NOR emulator. `--measure` skips the
optimized lookup bound so the previous core can be measured with the same test.

Coverage includes 64/256/1024/4096 sectors, contiguous and alternating fragmented
chains, creation and overwrite, and write sizes of 17 bytes, 4 KiB, 64 KiB or
the entire file. Fixtures own the intervening sectors through a separate blocker
file; tests check both files after remount. Existing data differs from replacement
data, preventing an omitted overwrite from passing readback. Validation counts
are checked separately against the expected full walks for the given calls.

For a 16 MiB file written in one call, position lookup drops from 8,386,560
map link loads to 4,095, for both contiguous and fragmented layouts. A full-file
overwrite still validates 4,096 links before writing. With separate 4 KiB
overwrite calls, validation still loads 16,777,216 links in total; position lookup
drops from 8,386,560 to zero. This optimization does not make all small-call I/O
linear, and these counters do not measure allocator scans or cartridge time.

Further cases cover long gap/truncate extension, fragmented seeks in both
directions with a dirty buffer, truncate followed by reallocation, and cursor
restart after read/erase/program failures. A live valid relink between writes
must be followed correctly; corruption in a later link must be rejected even
when the next write would hit the current dirty buffer, before flash callbacks.
The ordinary corruption, I/O, ownership and single-programming tests run alongside
this harness in `make check`.
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

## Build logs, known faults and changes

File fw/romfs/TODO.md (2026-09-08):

# ROMFS TODO

## Восстановление после отключения питания

Отложенная задача, обсуждена 2026-09-08. Сначала завершить сквозную обработку
ошибок flash I/O и частичных записей. Схему восстановления реализовывать после
отдельного согласования; пункты ниже — предложение для проработки.

- [ ] Хранить резервные копии `flashmap` и `flashlist` в служебных файлах,
  сохранив основные таблицы по прежним адресам и прежний формат записей ROMFS.
  Каждое поколение должно содержать согласованную пару таблиц. Предпочтительный
  вариант — два заранее выделенных файла, обновляемых по очереди, с возрастающим
  номером поколения в заголовке вместо неограниченного создания новых файлов.
- [ ] Определить заголовок снимка: сигнатура, версия, геометрия файловой системы,
  номер поколения, размеры, контрольная сумма заголовка и таблиц, признак
  завершения. Прерванная запись не должна приниматься за готовое поколение.
- [ ] Обеспечить обнаружение и чтение снимков без исправных основных
  `flashlist`/`flashmap`: например, выделить непрерывные области, обнаруживаемые
  прямым чтением flash по проверяемым заголовкам. Записи служебных файлов должны
  защищать эти области от выделения обычным файлам и от GC. Продумать первое
  включение механизма на существующем образе и нехватку места для резервов.
- [ ] Использовать защиту `SYSTEM | READONLY` и скрывать файлы снимков в
  пользовательских интерфейсах. Отдельного бита `hidden` сейчас нет: все три
  бита режима заняты `READONLY`, `SYSTEM`, `RESERVED`. Не расширять поле атрибутов
  без отдельного решения о совместимости.
- [ ] Проработать порядок фиксации: записать новые данные, записать следующее
  поколение снимка, проверить его чтением, последним записать признак завершения,
  затем обновить основные таблицы. До завершения нового поколения сохранять
  предыдущее. Способ записи признака завершения проверить с учётом ограничений
  erase/program конкретных flash-чипов и существующих callbacks.
- [ ] При загрузке выбирать последнее полностью записанное и проверенное
  поколение и восстанавливать основные таблицы; восстановление должно допускать
  повторное отключение питания. Определить поведение при отсутствии валидных
  снимков, повреждённых заголовках и переполнении номера поколения.
- [ ] Разделить защиту метаданных и данных файлов. Для сохранности данных при
  overwrite, append в неполный сектор и truncate нужна запись изменяемого сектора
  в новое место. Не переиспользовать сектора, необходимые предыдущему поколению,
  до фиксации нового. Одних копий таблиц для восстановления перезаписанных данных
  недостаточно.
- [ ] Определить совместимость со старыми прошивками и host-утилитами. Чтение
  завершённого образа использует прежние основные таблицы. Старые писатели не
  обновляют снимки, поэтому автоматическое восстановление устаревшей копии может
  потерять их изменения. Гарантии восстановления требуют поддержки протокола
  всеми писателями либо явно согласованного ограничения их использования.
- [ ] Добавить тесты прерывания erase/program на каждом этапе, включая частичную
  запись сектора, признак завершения, обновление основных таблиц и восстановление.
  Проверять согласованность таблиц и данных, сохранность предыдущего поколения,
  отсутствие двойного выделения секторов и работу на поддерживаемых геометриях.

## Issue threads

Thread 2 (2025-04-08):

The following device has no driver

jemus803, 2025-04-08:
Hi Thanks for an awesome project I really excited to get it work but I got one issue with the windows driver. I'm using v3 version but windows unable to find the driver for N64cart. it actually detect the device but no driver. do you know how can I find the driver please?

Many Thanks!

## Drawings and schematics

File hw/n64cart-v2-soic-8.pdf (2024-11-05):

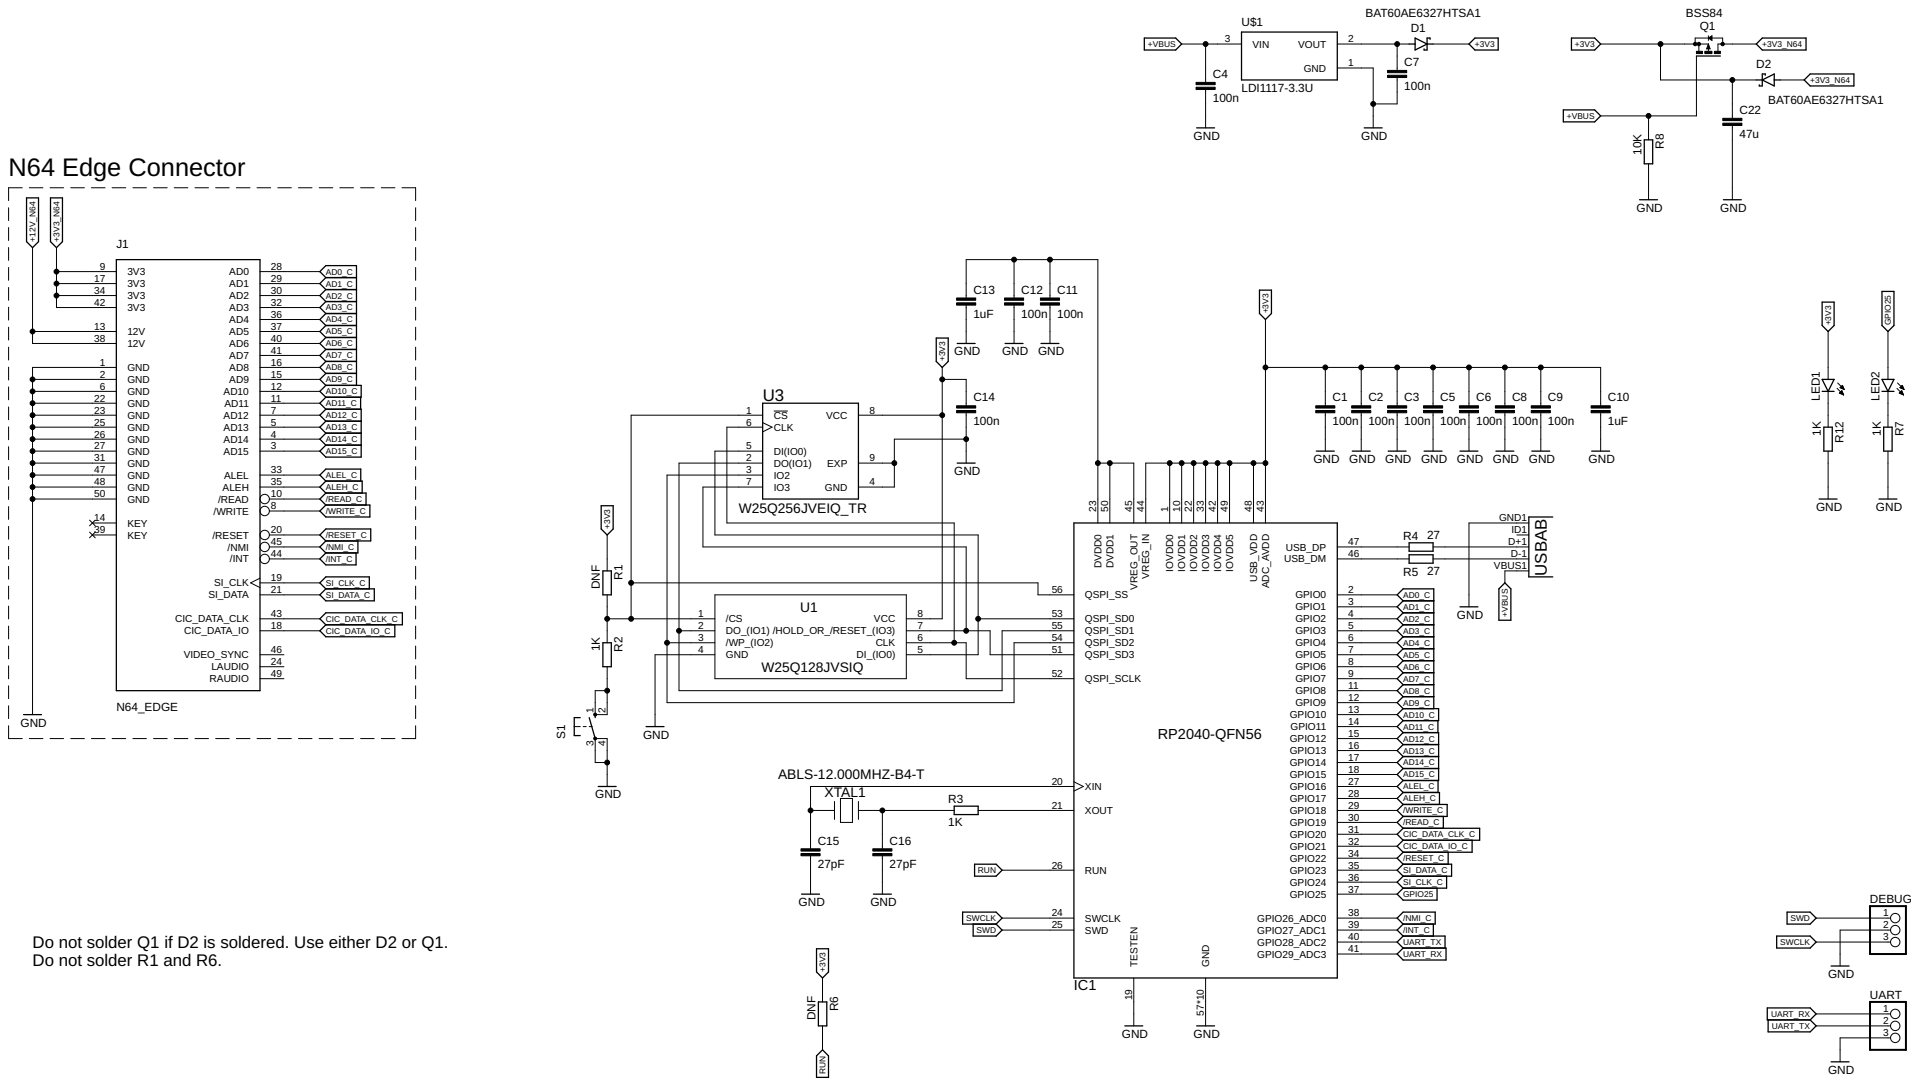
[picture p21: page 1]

Do not solder Q1 if D2 is soldered. Use either D2 or Q1. Do not solder R1 and R6.

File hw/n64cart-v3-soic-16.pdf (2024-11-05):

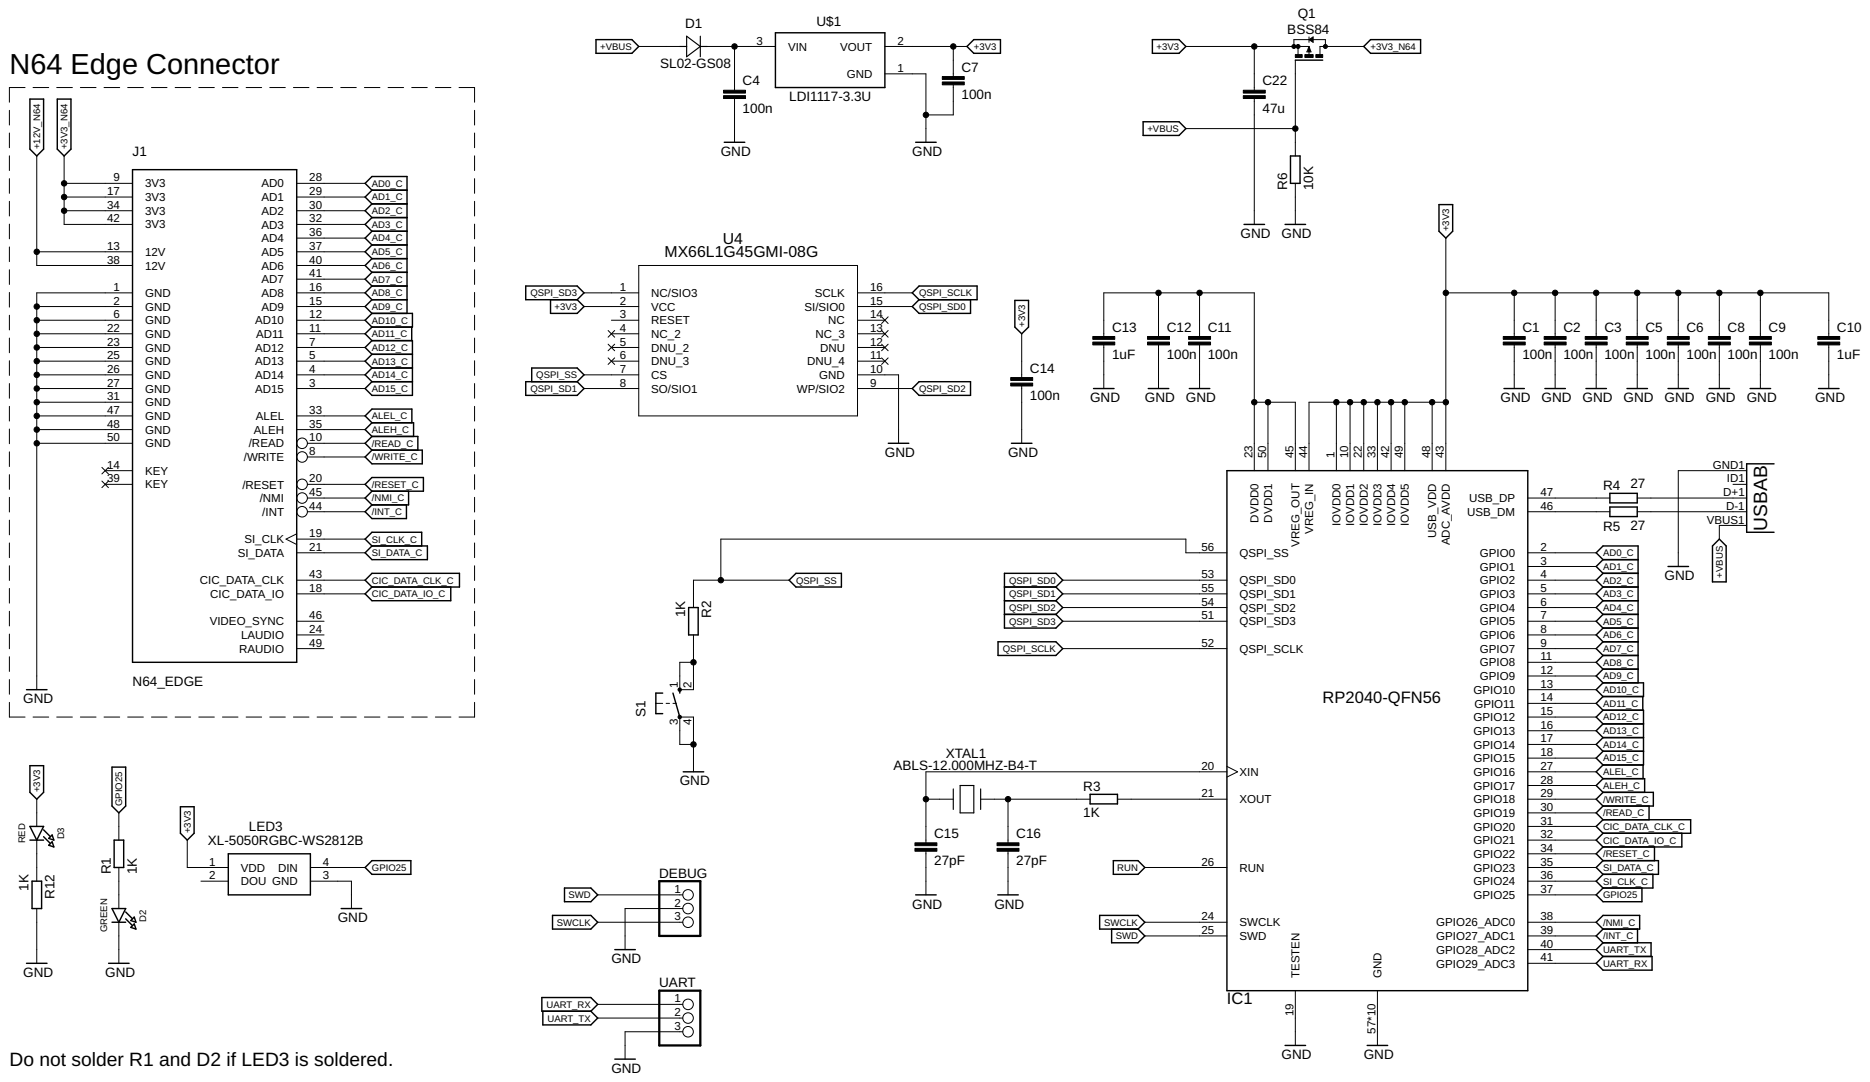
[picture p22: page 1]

Do not solder R1 and D2 if LED3 is soldered.

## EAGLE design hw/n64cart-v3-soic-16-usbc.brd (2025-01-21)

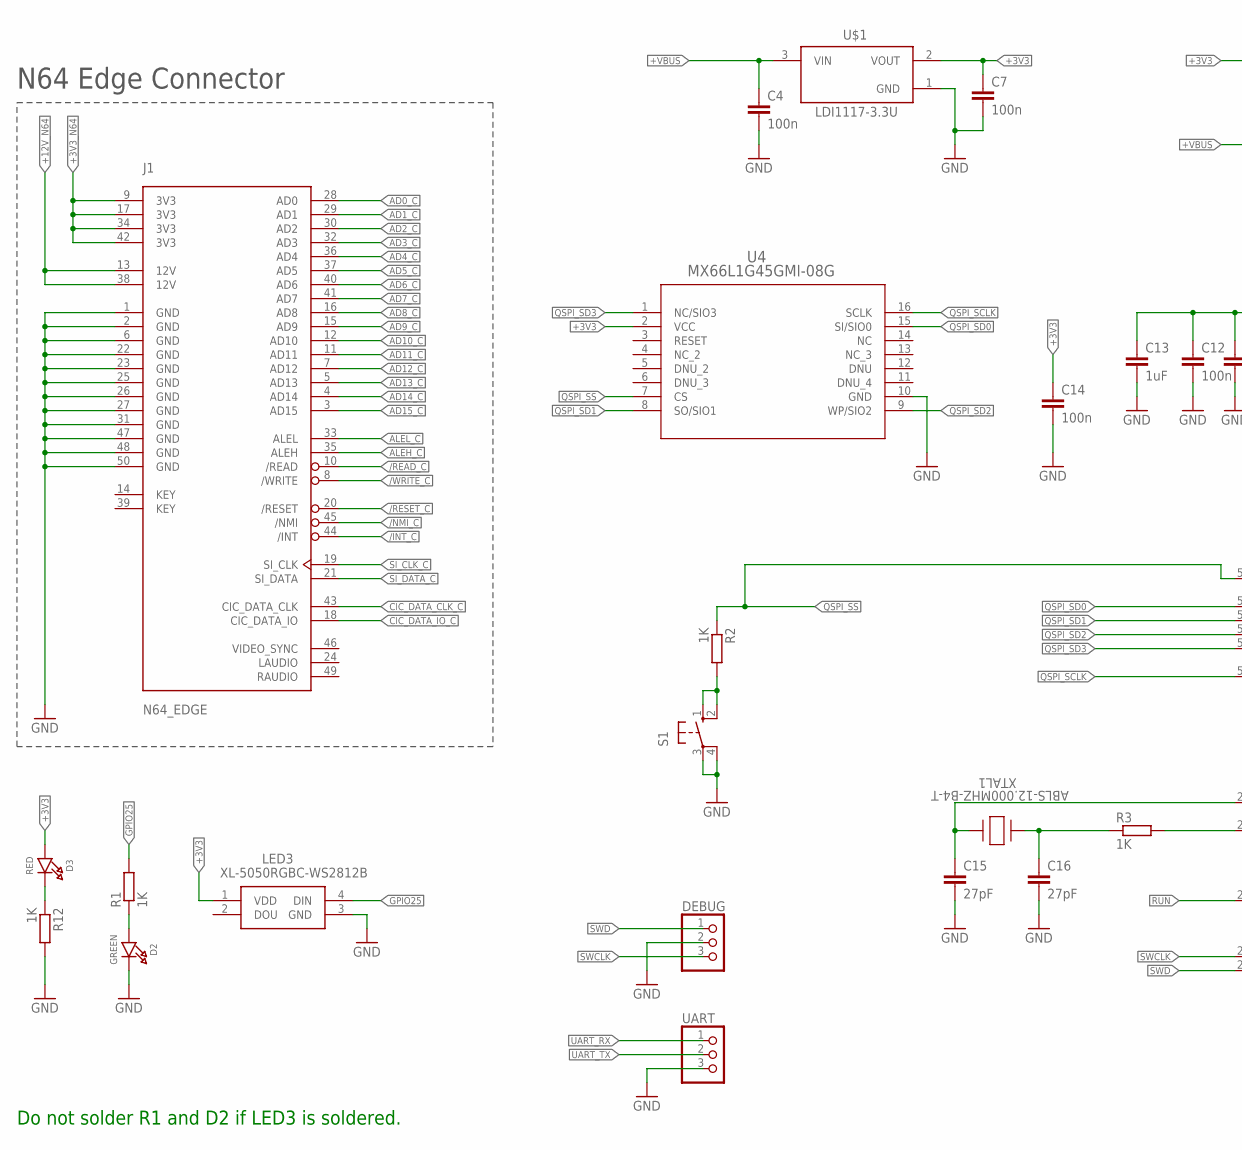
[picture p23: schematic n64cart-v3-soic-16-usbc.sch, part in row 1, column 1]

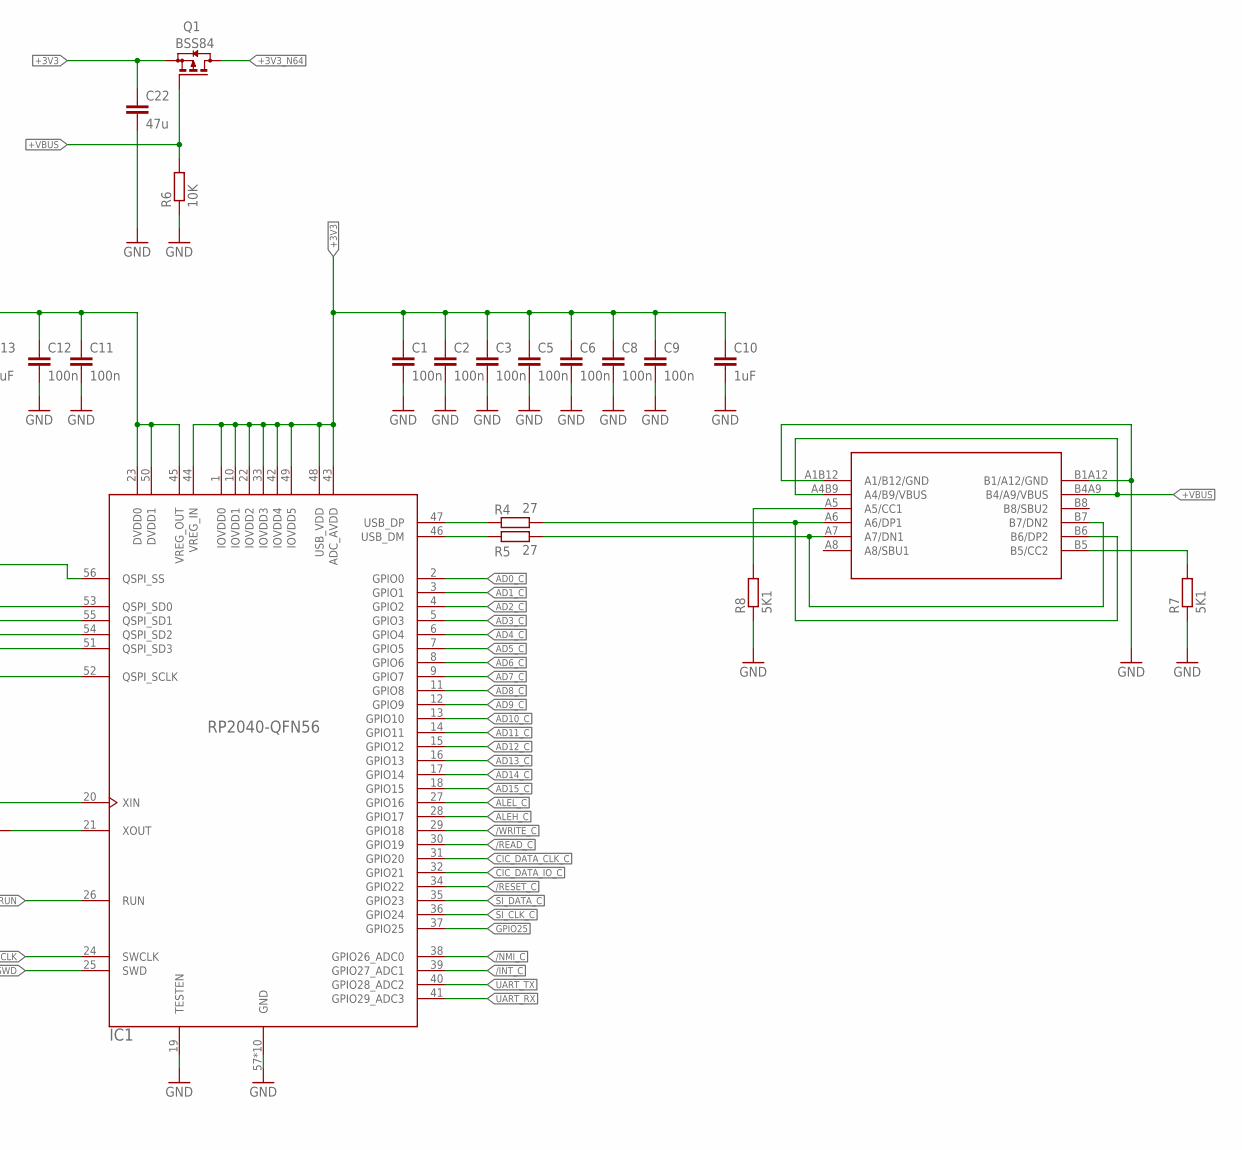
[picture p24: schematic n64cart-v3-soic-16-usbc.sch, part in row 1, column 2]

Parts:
C1, C2, C3, C5, C6, C8, C9, C11, C12, C14: 100n; C0402
C4, C7: 100n; C0603
C10, C13: 1uF; C0402
C15, C16: 27pF; C0402
C22: 47u; C0805
D2: GREEN; CHIPLED_0603_NOOUTLINE
D3: RED; CHIPLED_0603_NOOUTLINE
DEBUG: PINHD-1X3; 1X03
IC1: RP2040-QFN56; RP2040-QFN-56
J1: N64_EDGE
J2: GT-USB-7010
LED3: XL-5050RGBC-WS2812B; XL5050RGBCWS2812B
Q1: BSS84; SOT23
R1, R12: 1K; R0603
R2, R3: 1K; R0402
R4, R5: 27; R0402
R6: 10K; R0603
R7, R8: 5K1; R0603
S1: 10-XX; B3F-10XX
U4: MX66L1G45GMI-08G; SOP_16L_300_MAC-L
U$1: LDI1117-3.3U
UART: PINHD-1X3; 1X03
XTAL1: ABLS-12.000MHZ-B4-T; XTAL_ABLS_ABR

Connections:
+3V3: C1.1, C2.1, C3.1, C5.1, C6.1, C7.1, C8.1, C9.1, C10.1, C14.1, C22.1, D3.A, IC1.1 (IOVDD0), IC1.10 (IOVDD1), IC1.22 (IOVDD2), IC1.33 (IOVDD3), IC1.42 (IOVDD4), IC1.43 (ADC_AVDD), IC1.44 (VREG_IN), IC1.48 (USB_VDD), IC1.49 (IOVDD5), LED3.1 (VDD), Q1.2 (S), U4.2 (VCC), U$1.2 (VOUT)
+3V3_N64: J1.9 (3V3), J1.17 (3V3), J1.34 (3V3), J1.42 (3V3), Q1.3 (D)
+12V_N64: J1.13 (12V), J1.38 (12V)
+VBUS: C4.1, J2.A4B9 (A4/B9/VBUS), J2.B4A9 (B4/A9/VBUS), Q1.1 (G), R6.2, U$1.3 (VIN)
/INT_C: IC1.39 (GPIO27_ADC1), J1.44 (/INT)
/NMI_C: IC1.38 (GPIO26_ADC0), J1.45 (/NMI)
/READ_C: IC1.30 (GPIO19), J1.10 (/READ)
/RESET_C: IC1.34 (GPIO22), J1.20 (/RESET)
/WRITE_C: IC1.29 (GPIO18), J1.8 (/WRITE)
AD0_C: IC1.2 (GPIO0), J1.28 (AD0)
AD1_C: IC1.3 (GPIO1), J1.29 (AD1)
AD2_C: IC1.4 (GPIO2), J1.30 (AD2)
AD3_C: IC1.5 (GPIO3), J1.32 (AD3)
AD4_C: IC1.6 (GPIO4), J1.36 (AD4)
AD5_C: IC1.7 (GPIO5), J1.37 (AD5)
AD6_C: IC1.8 (GPIO6), J1.40 (AD6)
AD7_C: IC1.9 (GPIO7), J1.41 (AD7)
AD8_C: IC1.11 (GPIO8), J1.16 (AD8)
AD9_C: IC1.12 (GPIO9), J1.15 (AD9)
AD10_C: IC1.13 (GPIO10), J1.12 (AD10)
AD11_C: IC1.14 (GPIO11), J1.11 (AD11)
AD12_C: IC1.15 (GPIO12), J1.7 (AD12)
AD13_C: IC1.16 (GPIO13), J1.5 (AD13)
AD14_C: IC1.17 (GPIO14), J1.4 (AD14)
AD15_C: IC1.18 (GPIO15), J1.3 (AD15)
ALEH_C: IC1.28 (GPIO17), J1.35 (ALEH)
ALEL_C: IC1.27 (GPIO16), J1.33 (ALEL)
CIC_DATA_CLK_C: IC1.31 (GPIO20), J1.43 (CIC_DATA_CLK)
CIC_DATA_IO_C: IC1.32 (GPIO21), J1.18 (CIC_DATA_IO)
GND: C1.2, C2.2, C3.2, C4.2, C5.2, C6.2, C7.2, C8.2, C9.2, C10.2, C11.2, C12.2, C13.2, C14.2, C15.2, C16.2, C22.2, D2.C, DEBUG.2, IC1.19 (TESTEN), IC1.57 (GND), IC1.58 (GND), IC1.59 (GND), IC1.60 (GND), IC1.61 (GND), IC1.62 (GND), IC1.63 (GND), IC1.64 (GND), IC1.65 (GND), IC1.66 (GND), J1.1 (GND), J1.2 (GND), J1.6 (GND), J1.22 (GND), J1.23 (GND), J1.25 (GND), J1.26 (GND), J1.27 (GND), J1.31 (GND), J1.47 (GND), J1.48 (GND), J1.50 (GND), J2.A1B12 (A1/B12/GND), J2.B1A12 (B1/A12/GND), LED3.3 (GND), R6.1, R7.1, R8.1, R12.2, S1.3, S1.4 (P1), U4.10 (GND), U$1.1 (GND), UART.3
GPIO25: IC1.37 (GPIO25), LED3.4 (DIN), R1.2
unnamed: J2.B5 (B5/CC2), R7.2
unnamed: J2.A5 (A5/CC1), R8.2
unnamed: D3.C, R12.1
unnamed: C11.1, C12.1, C13.1, IC1.23 (DVDD0), IC1.45 (VREG_OUT), IC1.50 (DVDD1)
unnamed: J2.A7 (A7/DN1), J2.B7 (B7/DN2), R5.2
unnamed: J2.A6 (A6/DP1), J2.B6 (B6/DP2), R4.2
unnamed: D2.A, R1.1
unnamed: R2.2, S1.1 (S), S1.2 (S1)
unnamed: C16.1, R3.1, XTAL1.1
unnamed: C15.1, IC1.20 (XIN), XTAL1.2
unnamed: IC1.21 (XOUT), R3.2
unnamed: IC1.47 (USB_DP), R4.1
unnamed: IC1.46 (USB_DM), R5.1
QSPI_SCLK: IC1.52 (QSPI_SCLK), U4.16 (SCLK)
QSPI_SD0: IC1.53 (QSPI_SD0), U4.15 (SI/SIO0)
QSPI_SD1: IC1.55 (QSPI_SD1), U4.8 (SO/SIO1)
QSPI_SD2: IC1.54 (QSPI_SD2), U4.9 (WP/SIO2)
QSPI_SD3: IC1.51 (QSPI_SD3), U4.1 (NC/SIO3)
QSPI_SS: IC1.56 (QSPI_SS), R2.1, U4.7 (CS)
RUN: IC1.26 (RUN)
SI_CLK_C: IC1.36 (GPIO24), J1.19 (SI_CLK)
SI_DATA_C: IC1.35 (GPIO23), J1.21 (SI_DATA)
SWCLK: DEBUG.3, IC1.24 (SWCLK)
SWD: DEBUG.1, IC1.25 (SWD)
UART_RX: IC1.41 (GPIO29_ADC3), UART.1
UART_TX: IC1.40 (GPIO28_ADC2), UART.2

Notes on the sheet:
N64 Edge Connector
Do not solder R1 and D2 if LED3 is soldered.

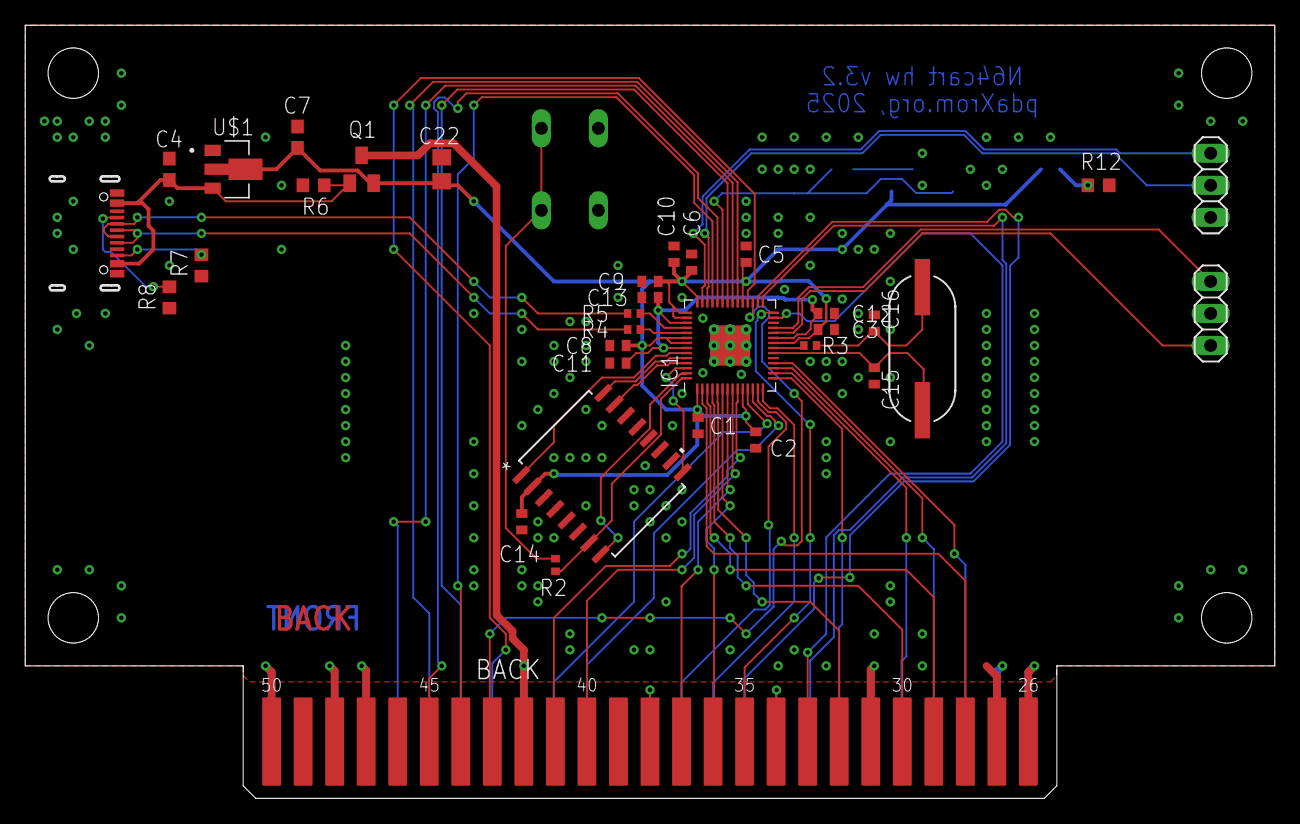
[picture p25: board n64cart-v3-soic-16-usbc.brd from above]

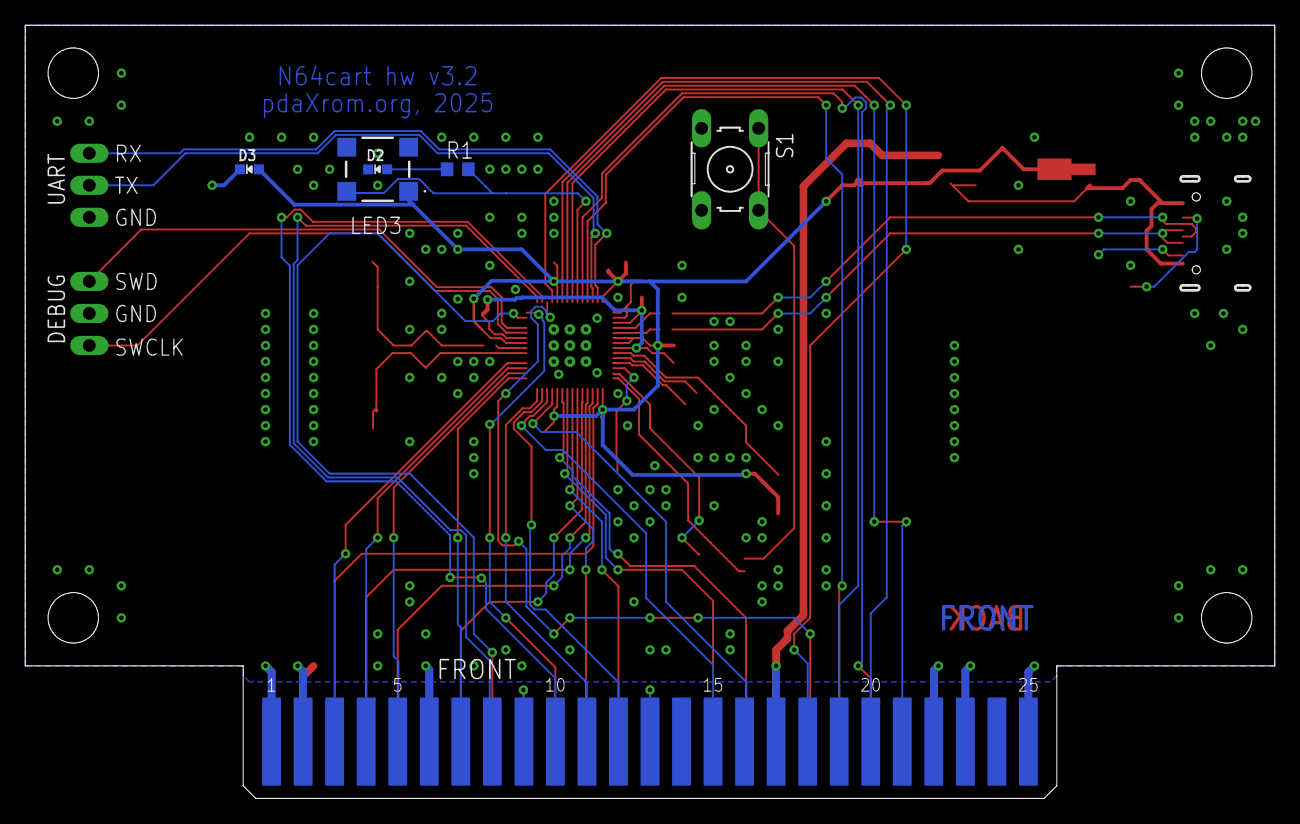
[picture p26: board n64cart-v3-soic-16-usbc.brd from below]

Board: 2 copper layers, 99.1 x 61.3 mm, 39 parts (5 on the bottom side), 56 nets.

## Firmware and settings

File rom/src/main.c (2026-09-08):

/**
 * Copyright (c) 2022-2026 sashz /pdaXrom.org/
 *
 * SPDX-License-Identifier: BSD-3-Clause
 */

#include <ctype.h>
#include <stdbool.h>
#include <libdragon.h>
#include <malloc.h>
#include <stdint.h>
#include <stdio.h>
#include <stdlib.h>
#include <dir.h>
#include <errno.h>
#include <string.h>
#include <sys/stat.h>
#include <unistd.h>

#include "../../fw/romfs/romfs.h"
#include "../../fw/romfs/romfs_flash.h"
#include "../../fw/romfs/newlib-romfs.h"
#include "ext/shell_utils.h"
#include "n64cart.h"
#ifdef WITH_FONT_FILE
#include WITH_FONT_FILE
#else
#include "../build/wy700font-regular.h"
#endif
#ifdef WITH_USB_ICON_FILE
#include WITH_USB_ICON_FILE
#endif
#include "main.h"
#include "usb/usbd.h"

#include "syslog.h"
#include "md5.h"
#include "imgviewer.h"

#define FILE_NAME_SCROLL_DELAY  (5)
#define KEYS_DELAY (3)
#define USB_ROMFS_RELOAD_DELAY_FRAMES 30
#define USB_DISPLAY_ACTIVITY_HOLD_MS 1000

static void update_romfs_free_text(void);
static void update_path_text(void);
static bool reload_romfs_view(void);
static bool usb_romfs_reload_pending(void);
static bool handle_usb_romfs_reload(display_context_t disp);
static bool allocate_manager_buffers(bool is_hires);
static void load_background_image(void);
static bool ensure_image_decode_arena(void);
static bool allocate_image_decode_arena(bool is_hires);

enum {
    STEP_LOGO = 0,
    STEP_ROMFS_INIT,
    STEP_LOAD_BACKGROUND,
    STEP_SAVE_GAMESAVE,
    //STEP_USB_INIT,
    STEP_FINISH
};

static const struct flash_chip flash_chip[] = {
    { 0xc2, 0x201b, 128, "MX66L1G45G" },
    { 0xef, 0x4020, 64, "W25Q512" },
    { 0xef, 0x4019, 32, "W25Q256" },
    { 0xef, 0x4018, 16, "W25Q128" },
    { 0xef, 0x4017, 8, "W25Q64" },
    { 0xef, 0x4016, 4, "W25Q32" },
    { 0xef, 0x4015, 2, "W25Q16" }
};

static const struct flash_chip *used_flash_chip = NULL;

static int scr_width;
static int scr_height;
static int scr_scale;

static volatile int usb_display_mode_request = -1;
static volatile bool usb_display_mode_session = false;
static volatile bool usb_display_activity_active = false;
static volatile uint32_t usb_display_activity_deadline = 0;
static volatile bool usb_romfs_modified = false;
static volatile bool usb_romfs_reload_request = false;
static volatile int usb_romfs_reload_delay = 0;
static bool usb_display_mode_active = false;
static bool usb_display_splash_drawn = false;
#ifdef WITH_USB_ICON_FILE
static struct {
    sprite_t sprite;
    uint32_t data[USB_ICON_WIDTH * USB_ICON_HEIGHT];
} usb_icon_sprite_storage;
static bool usb_icon_sprite_ready = false;
#endif

#define ROMFS_PATH_MAX 256

static struct File_Rec {
    char name[ROMFS_MAX_NAME_LEN]; // base entry name (no path)
    char path[ROMFS_PATH_MAX];     // full path from root (no trailing slash)
    size_t size;
    int scroll_pos;
    int scroll_dir;
    int scroll_delay;
    bool is_dir;
    bool is_parent;
} files[128];

static int num_files = 0;
static int menu_sel = 0;

static int dir_depth = 0; // 0 == root
static char current_path[ROMFS_PATH_MAX];
static char txt_romfs_free[64];
static char txt_current_path[ROMFS_PATH_MAX];

static uint8_t __attribute__((aligned(16))) save_data[131072];

static sprite_t *bg_img = NULL;
static sprite_t *bg_img_buffer = NULL;
static size_t bg_img_buffer_size = 0;
static uint8_t *image_decode_arena = NULL;
static size_t image_decode_arena_size = 0;
static uint16_t *romfs_flash_map = NULL;
static uint8_t *romfs_flash_list = NULL;
static uint32_t romfs_flash_map_size = 0;
static uint32_t romfs_flash_list_size = 0;
static bool romfs_ready = false;

static int do_step = STEP_LOGO;

static bool force_fram = false;

static int flash_access_lock_depth;
static bool flash_access_restore_cart;

static void flash_access_lock(void)
{
    if (flash_access_lock_depth++ == 0) {
        flash_access_restore_cart = (C0_STATUS() & C0_INTERRUPT_CART) != 0;
        set_CART_interrupt(0);
    }
}

static void flash_access_unlock(void)
{
    if (flash_access_lock_depth <= 0) {
        flash_access_lock_depth = 0;
        return;
    }

    if (--flash_access_lock_depth == 0) {
        set_CART_interrupt(flash_access_restore_cart);
    }
}

uint32_t get_romfs_start_offset(void)
{
    return romfs_align_flash_start(n64cart_fw_size());
}

bool romfs_flash_sector_writable(uint32_t offset)
{
    return used_flash_chip && romfs_flash_sector_in_range(offset, get_romfs_start_offset(),
                                                         used_flash_chip->rom_size * ROMFS_MB);
}

bool romfs_flash_sector_erase(uint32_t offset)
{
#ifdef DEBUG_FS
    syslog(LOG_DEBUG, "%s: offset %08X", __func__, offset);
#endif
    if (!romfs_flash_sector_writable(offset)) {
        return false;
    }
    flash_access_lock();
    flash_mode(0);
    bool result = flash_erase_sector(offset);
    flash_mode(1);
    flash_access_unlock();

    return result;
}

bool romfs_flash_sector_write(uint32_t offset, uint8_t *buffer)
{
#ifdef DEBUG_FS
    syslog(LOG_DEBUG, "%s: offset %08X", __func__, offset);
#endif
    if (!buffer || !romfs_flash_sector_writable(offset)) {
        return false;
    }
    flash_access_lock();
    flash_mode(0);
    bool result = flash_write_sector(offset, buffer);
    flash_mode(1);
    flash_access_unlock();

    return result;
}

bool romfs_flash_sector_read(uint32_t offset, uint8_t *buffer, uint32_t need)
{
#ifdef DEBUG_FS
    syslog(LOG_DEBUG, "%s: offset %08lX, need %ld", __func__, offset, need);
#endif
    flash_access_lock();
    flash_mode(0);
    flash_read(offset, buffer, need);
    flash_mode(1);
    flash_access_unlock();

    return true;
}

static int valign(const char *s)
{
    return (scr_width >> 1) - strlen(s) * 4 * scr_scale;
}

static void detect_flash_chip()
{
    uint8_t rxbuf[4];

    flash_access_lock();
    flash_mode(0);
    flash_do_cmd(0x9f, NULL, rxbuf, 4);
    flash_mode(1);
    flash_access_unlock();

    syslog(LOG_INFO, "Flash jedec id %02X %02X %02X", rxbuf[0], rxbuf[1], rxbuf[2]);

    uint8_t mf = rxbuf[0];
    uint16_t id = (rxbuf[1] << 8) | rxbuf[2];

    used_flash_chip = NULL;
    for (int i = 0; i < sizeof(flash_chip) / sizeof(struct flash_chip); i++) {
        if (flash_chip[i].mf == mf && flash_chip[i].id == id) {
            used_flash_chip = &flash_chip[i];
            break;
        }
    }
}

const struct flash_chip *get_flash_info()
{
    return used_flash_chip;
}

void n64cart_set_usb_display_mode(bool active)
{
    if (active) {
        syslog(LOG_INFO, "USB display mode: SPI session begin");
        usb_display_mode_session = true;
    } else if (usb_display_mode_session) {
        usb_display_mode_session = false;
        if (usb_romfs_modified) {
            syslog(LOG_INFO, "USB display mode: SPI session end, schedule ROMFS reload");
            usb_romfs_modified = false;
            usb_romfs_reload_request = true;
            usb_romfs_reload_delay = USB_ROMFS_RELOAD_DELAY_FRAMES;
        } else {
            syslog(LOG_INFO, "USB display mode: SPI session end, no ROMFS changes");
        }
    }
    usb_display_mode_request = (active || usb_display_activity_active) ? 1 : 0;
}

void n64cart_note_usb_activity(void)
{
    usb_display_activity_active = true;
    usb_display_activity_deadline = TICKS_READ() + TICKS_FROM_MS(USB_DISPLAY_ACTIVITY_HOLD_MS);
    usb_display_mode_request = 1;
}

void n64cart_note_usb_romfs_modified(void)
{
    if (!usb_romfs_modified) {
        syslog(LOG_INFO, "USB ROMFS modified");
    }
    usb_romfs_modified = true;
}

static void init_manager_display(bool is_hires)
{
    display_init(is_hires ? RESOLUTION_640x480 : RESOLUTION_320x240, DEPTH_32_BPP, 2, GAMMA_NONE, FILTERS_RESAMPLE);

    if (is_hires) {
        graphics_set_font_sprite((sprite_t *) wy700font_regular_sprite);
        scr_scale = 2;
    } else {
        scr_scale = 1;
    }

    scr_width = display_get_width();
    scr_height = display_get_height();
}

static void stabilize_display_pairs(display_context_t disp)
{
    if (!disp || disp->height <= 240 || surface_get_format(disp) != FMT_RGBA32) {
        return;
    }

    uint8_t *buffer = disp->buffer;
    for (int y = 0; y + 1 < disp->height; y += 2) {
        memmove(buffer + (size_t)(y + 1) * disp->stride, buffer + (size_t)y * disp->stride, disp->stride);
    }
}

static void draw_usb_display_splash(display_context_t disp)
{
    graphics_fill_screen(disp, 0);

#ifdef WITH_USB_ICON_FILE
    if (!usb_icon_sprite_ready) {
        usb_icon_sprite_storage.sprite.width = USB_ICON_WIDTH;
        usb_icon_sprite_storage.sprite.height = USB_ICON_HEIGHT;
        usb_icon_sprite_storage.sprite.flags = FMT_RGBA32;
        usb_icon_sprite_storage.sprite.hslices = 1;
        usb_icon_sprite_storage.sprite.vslices = 1;
        memmove(usb_icon_sprite_storage.data, n64cart_icon_rgba, sizeof(usb_icon_sprite_storage.data));
        usb_icon_sprite_ready = true;
    }

    sprite_t *icon = &usb_icon_sprite_storage.sprite;
    int x = (scr_width - icon->width) / 2;
    int y = (scr_height - icon->height) / 2;
    y &= ~1;
    graphics_draw_sprite(disp, x < 0 ? 0 : x, y < 0 ? 0 : y, icon);
#endif
}

static void show_usb_display_splash(display_context_t disp)
{
    draw_usb_display_splash(disp);
    stabilize_display_pairs(disp);
    display_show(disp);
    usb_display_splash_drawn = true;
    usbd_complete_pending_spi_mode();
}

static void apply_usb_display_mode_request(void)
{
    int request = usb_display_mode_request;
    if (request < 0) {
        return;
    }

    bool active = request != 0;
    usb_display_mode_request = -1;
    if (usb_display_mode_active == active) {
        return;
    }

    syslog(LOG_INFO, "USB display mode: active=%d, keep display %dx%d", active, scr_width, scr_height);

    usb_display_mode_active = active;
    usb_display_splash_drawn = false;
}

static void update_usb_display_activity(void)
{
    if (!usb_display_activity_active || usb_display_mode_session) {
        return;
    }

    if (TICKS_BEFORE(TICKS_READ(), usb_display_activity_deadline)) {
        return;
    }

    usb_display_activity_active = false;
    usb_display_mode_request = 0;
}

static bool ensure_image_decode_arena(void)
{
    if (image_decode_arena) {
        image_set_decode_arena(image_decode_arena, image_decode_arena_size);
        return true;
    }

    const size_t hires_sizes[] = {
        2 * 1024 * 1024,
        1792 * 1024,
        1536 * 1024,
    };
    const size_t lores_sizes[] = {
        768 * 1024,
        512 * 1024,
    };

    const size_t *sizes = scr_width > 320 ? hires_sizes : lores_sizes;
    int num_sizes = scr_width > 320 ? (int)(sizeof(hires_sizes) / sizeof(hires_sizes[0])) :
                    (int)(sizeof(lores_sizes) / sizeof(lores_sizes[0]));

    for (int i = 0; i < num_sizes; i++) {
        image_decode_arena_size = sizes[i];
        image_decode_arena = malloc(image_decode_arena_size);
        if (image_decode_arena) {
            image_set_decode_arena(image_decode_arena, image_decode_arena_size);
            return true;
        }
        syslog(LOG_INFO, "image decode arena size unavailable: %lu", (unsigned long)image_decode_arena_size);
    }

    syslog(LOG_ERR, "Cannot allocate image decode arena");
    image_decode_arena_size = 0;
    image_set_decode_arena(NULL, 0);
    return false;
}

static bool allocate_image_decode_arena(bool is_hires)
{
    if (image_decode_arena) {
        return true;
    }

    const size_t hires_sizes[] = {
        2 * 1024 * 1024,
        1920 * 1024,
        1792 * 1024,
        1536 * 1024,
    };
    const size_t lores_sizes[] = {
        512 * 1024,
    };

    const size_t *sizes = is_hires ? hires_sizes : lores_sizes;
    int num_sizes = is_hires ? (int)(sizeof(hires_sizes) / sizeof(hires_sizes[0])) :
                    (int)(sizeof(lores_sizes) / sizeof(lores_sizes[0]));

    for (int i = 0; i < num_sizes; i++) {
        image_decode_arena_size = sizes[i];
        image_decode_arena = malloc(image_decode_arena_size);
        if (image_decode_arena) {
            image_set_decode_arena(image_decode_arena, image_decode_arena_size);
            syslog(LOG_INFO, "image decode arena allocated");
            return true;
        }

        syslog(LOG_INFO, "image decode arena size unavailable: %lu", (unsigned long)sizes[i]);
    }

    image_decode_arena_size = 0;
    image_set_decode_arena(NULL, 0);
    return false;
}

static bool allocate_manager_buffers(bool is_hires)
{
    int max_width = is_hires ? 640 : 320;
    int max_height = is_hires ? 480 : 240;

    allocate_image_decode_arena(is_hires);

    bg_img_buffer_size = sizeof(sprite_t) + (size_t)max_width * max_height * 4;
    bg_img_buffer = malloc(bg_img_buffer_size);
    if (!bg_img_buffer) {
        syslog(LOG_ERR, "Cannot allocate background buffer");
        return false;
    }

    if (used_flash_chip) {
        romfs_get_buffers_sizes(used_flash_chip->rom_size * 1024 * 1024, &romfs_flash_map_size, &romfs_flash_list_size);

        romfs_flash_map = malloc(romfs_flash_map_size);
        romfs_flash_list = malloc(romfs_flash_list_size);

        if (!romfs_flash_map || !romfs_flash_list) {
            syslog(LOG_ERR, "Cannot allocate ROMFS buffers");
            return false;
        }
    }

    return true;
}
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
int main(void)
{
    syslog(LOG_INFO, "N64cart manager fw v%d.%d (" GIT_HASH ") by pdaXrom!", FIRMWARE_VERSION / 256,
           FIRMWARE_VERSION % 256);
    usbd_start();

    bool is_hires = is_memory_expanded();

    int font_width = 8;

    joypad_init();

    dma_wait();

    io_write(N64CART_LED_CTRL, 0);

    detect_flash_chip();

    allocate_manager_buffers(is_hires);
    init_manager_display(is_hires);

    if (used_flash_chip) {
        syslog(LOG_INFO, "Flash chip: %s (%d MB)", used_flash_chip->name, used_flash_chip->rom_size);
    }

    syslog(LOG_INFO, "N64Cart fw size: %ld", n64cart_fw_size());

    static const char *txt_title_1 = "N64CART MANAGER";
    static const char *txt_title_2 = "(c) sashz /pdaXrom.org/, 2022-2026";
    static char txt_rom_info[128];
    static const char *txt_menu_info_1 = "[UP]/[DOWN]-Select, [L]/[R]-Page";
#ifdef NO_FILE_DELETION
    static const char *txt_menu_info_2 = "[A]-Run";
#else
    static const char *txt_menu_info_2 = "[A]-Run, [C-L]-Delete";
#endif

    if (used_flash_chip) {
        snprintf(txt_rom_info, sizeof(txt_rom_info) - 1, "Flash chip: %s (%d MB)", used_flash_chip->name,
                 used_flash_chip->rom_size);
    } else {
        strncpy(txt_rom_info, "Unknown flash chip", sizeof(txt_rom_info) - 1);
    }

    static const char *tv_type_str[] = { "PAL", "NTSC", "M-PAL" };
    static char txt_tv_type_msg[64];

    static display_context_t disp = 0;

    bool hide_menu = false;

    do_step = STEP_LOGO;

    int keys_delay_counter = 0;

    /* Main loop test */
    while (1) {
        update_usb_display_activity();
        apply_usb_display_mode_request();

        if (usb_display_mode_active) {
            if (!usb_display_splash_drawn) {
                disp = display_get();
                show_usb_display_splash(disp);
            } else {
                usbd_complete_pending_spi_mode();
            }
            continue;
        }

        disp = display_get();
        apply_usb_display_mode_request();
        if (usb_display_mode_active) {
            show_usb_display_splash(disp);
            continue;
        }

        if (handle_usb_romfs_reload(disp)) {
            continue;
        }

        /* Create Place for Text */
        char tStr[256];

        if (bg_img) {
            /* Logo */
            graphics_draw_sprite(disp, 0, 0, bg_img);
        } else {
            /* Fill the screen */
            graphics_fill_screen(disp, 0);
        }

        graphics_set_color(0xeeeeee00, 0x00000000);


        if (do_step == STEP_LOGO) {
            static int i = 0;
            if (++i < 30) {
                static char *logo_text = "pdaXrom";
                char text[strlen(logo_text) + 1];
                memset(text, 0, sizeof(text));

                strncpy(text, logo_text, (i + 1) / 2);
                graphics_draw_text(disp, valign(text), 120 * scr_scale, text);
                display_show(disp);

                continue;
            }

            do_step = STEP_ROMFS_INIT;
            display_show(disp);
            continue;
        }

        if (do_step == STEP_ROMFS_INIT) {
            static const char *save_data_txt = "ROM FS starting...";
            graphics_draw_text(disp, valign(save_data_txt), 120 * scr_scale, save_data_txt);
            display_show(disp);

            uint32_t fw_size = n64cart_fw_size();
            syslog(LOG_INFO, "flash_map: %d, flash_list: %d, fw_size: %d", romfs_flash_map_size, romfs_flash_list_size, fw_size);
            syslog(LOG_INFO, "flash_map  ptr %p", romfs_flash_map);
            syslog(LOG_INFO, "flash_list ptr %p", romfs_flash_list);

            if (!used_flash_chip || !romfs_flash_map || !romfs_flash_list ||
                    !romfs_start(fw_size, used_flash_chip->rom_size * 1024 * 1024, romfs_flash_map, romfs_flash_list)) {
                syslog(LOG_ERR, "Cannot start romfs!");
                romfs_ready = false;
            } else {
                if (newlib_romfs_init()) {
                    romfs_ready = true;
                    reset_directory_stack();
                    refresh_file_list();
                } else {
                    syslog(LOG_ERR, "Can't init newlib filesystem support!");
                    romfs_ready = false;
                }
                menu_sel = 0;
            }

            show_md5((uint8_t *)romfs_flash_map, romfs_flash_map_size);

            update_romfs_free_text();
            update_path_text();

            do_step = STEP_LOAD_BACKGROUND;
            continue;
        }

        if (do_step == STEP_LOAD_BACKGROUND) {
            static const char *save_data_txt = "Loading background...";
            graphics_draw_text(disp, valign(save_data_txt), 120 * scr_scale, save_data_txt);
            display_show(disp);

            load_background_image();

            do_step = STEP_SAVE_GAMESAVE;
            continue;
        }

        if (do_step == STEP_SAVE_GAMESAVE) {
            char save_name[64] = { 0 };
            uint32_t save_addr = 0;
            int save_size = 0;
            uint8_t md5_old[16];

            do_step = STEP_FINISH;

            // copy save data from cartridge on reset button and set default save data configuration
            syslog(LOG_INFO, "reset type %d", sys_reset_type());
            syslog(LOG_INFO, "switch to SRAM mode");
            n64cart_sram_mode();
            n64cart_sram_unlock();
            if (sys_reset_type() == RESET_WARM) {
                syslog(LOG_INFO, "get eeprom data");

                save_addr = io_read(N64CART_RMRAM);
                save_size = io_read(N64CART_RMRAM + 4);
                if (save_addr && save_size) {
                    for (int i = 0; i < sizeof(save_name); i += 4) {
                        *((uint32_t *) &save_name[i]) = io_read(N64CART_RMRAM + 8 + i);
                    }

                    for (int i = 0; i < 16; i += 4) {
                        *((uint32_t *) &md5_old[i]) = io_read(N64CART_RMRAM + 8 + sizeof(save_name) + i);
                    }

                    if (save_addr && save_size && save_name[0]) {
                        //              dma_wait();
                        //              data_cache_hit_writeback_invalidate(save_data, sizeof(save_data));
                        //              dma_read(save_data, N64CART_EEPROM, sizeof(save_data));
                        for (int i = 0; i < save_size; i += 4) {
                            *((uint32_t *) &save_data[i]) = io_read(save_addr + i);
                        }
                    }
                }
            }
            io_write(N64CART_RMRAM, 0);
            n64cart_sram_lock();
            n64cart_eeprom_16kbit(true);

            if (save_addr && save_size && save_name[0]) {
                graphics_draw_box(disp, 40 * scr_scale, 110 * scr_scale, (320 - 40 * 2) * scr_scale, 50 * scr_scale, 0x00000080);
                graphics_draw_box(disp, 45 * scr_scale, 115 * scr_scale, (320 - 45 * 2) * scr_scale, 40 * scr_scale, 0x77777780);

                static const char *save_data_txt = "Writing save file...";
                graphics_draw_text(disp, valign(save_data_txt), 120 * scr_scale, save_data_txt);
                display_show(disp);

                syslog(LOG_INFO, "save name: %s, pi_addr %08lX, size %d", save_name, save_addr, save_size);

                uint8_t md5_actual[16] = {0};
                calc_md5(save_data, save_size, md5_actual);
                print_bytes(md5_old, "old save file");
                print_bytes(md5_actual, "new save file");

                if (memcmp(md5_old, md5_actual, 16)) {
                    char save_full_path[ROMFS_PATH_MAX + 8];
                    build_romfs_prefixed_path(save_name, save_full_path, sizeof(save_full_path));

                    remove(save_full_path);
                    if (save_size <= 2048) {
                        // eeprom byte swap
                        for (int i = 0; i < save_size; i += 2) {
                            uint8_t tmp = save_data[i];
                            save_data[i] = save_data[i + 1];
                            save_data[i + 1] = tmp;
                        }
                    } else {
                        // sram word swap
                        for (int i = 0; i < save_size; i += 4) {
                            uint8_t tmp = save_data[i];
                            save_data[i] = save_data[i + 3];
                            save_data[i + 3] = tmp;
                            tmp = save_data[i + 2];
                            save_data[i + 2] = save_data[i + 1];
                            save_data[i + 1] = tmp;
                        }
                    }
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

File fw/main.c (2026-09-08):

/**
 * Copyright (c) 2022-2026 sashz /pdaXrom.org/
 *
 * SPDX-License-Identifier: BSD-3-Clause
 */

#include "main.h"

#include <stdio.h>
#include <string.h>

#include "flashrom.h"
#include "hardware/clocks.h"
#include "hardware/flash.h"
#include "hardware/vreg.h"
#include "hardware/structs/xip_ctrl.h"
#include "n64.h"
#include "n64_pi.h"
#include "pico/multicore.h"
#include "pico/stdio.h"
#include "pico/stdlib.h"
#include "romfs/romfs.h"
#include "romfs/romfs_flash.h"
#include "usb/usbd.h"
#include "n64_cic.h"
#include "n64_si.h"
#if defined(PICO_DEFAULT_LED_PIN) && (PICO_LED_WS2812 == 1)
#include "rgb_led.h"
#endif

static const struct flash_chip flash_chip[] = {
    { 0xc2, 0x201b, 128, 364000, VREG_VOLTAGE_1_20, "MX66L1G45G" },
    { 0xef, 0x4020, 64, 364000, VREG_VOLTAGE_1_20, "W25Q512" },
    { 0xef, 0x4019, 32, 364000, VREG_VOLTAGE_1_20, "W25Q256" },
    { 0xef, 0x4018, 16, 364000, VREG_VOLTAGE_1_20, "W25Q128" },
    { 0xef, 0x4017, 8, 364000, VREG_VOLTAGE_1_20, "W25Q64" },
    { 0xef, 0x4016, 4, 364000, VREG_VOLTAGE_1_20, "W25Q32" },
    { 0xef, 0x4015, 2, 364000, VREG_VOLTAGE_1_20, "W25Q16" },
};

static const struct flash_chip *used_flash_chip;

// #define DEBUG_FS 1

uint32_t get_romfs_start_offset(void)
{
    uint32_t fw_binary_size = (uintptr_t) &__flash_binary_end - XIP_BASE;

    return romfs_align_flash_start(fw_binary_size);
}

bool romfs_flash_sector_writable(uint32_t offset)
{
    return used_flash_chip && romfs_flash_sector_in_range(offset, get_romfs_start_offset(),
                                                         used_flash_chip->rom_size * ROMFS_MB);
}

bool romfs_flash_sector_erase(uint32_t offset)
{
#ifdef DEBUG_FS
    printf("%s: offset %08X\n", __func__, offset);
#endif
    return romfs_flash_sector_writable(offset) && flash_erase_sector(offset);
}

bool romfs_flash_sector_write(uint32_t offset, uint8_t *buffer)
{
#ifdef DEBUG_FS
    printf("%s: offset %08X\n", __func__, offset);
#endif
    return buffer && romfs_flash_sector_writable(offset) && flash_write_sector(offset, buffer);
}

bool romfs_flash_sector_read(uint32_t offset, uint8_t *buffer, uint32_t need)
{
#ifdef DEBUG_FS
    printf("%s: offset %08X\n", __func__, offset);
#endif
    flash_read(offset, buffer, need);

    return true;
}

static void flash_ls()
{
    romfs_file file;
    printf("File list:\n");
    if (romfs_list(&file, true) == ROMFS_NOERR) {
        do {
            printf("%s\t%d\t%0X %4X\n", file.entry.name, file.entry.size, file.entry.attr.names.mode, file.entry.attr.names.type);
        } while (romfs_list(&file, false) == ROMFS_NOERR);
    }
}

static void setup_sysconfig(void)
{
    uint8_t txbuf[4];
    uint8_t rxbuf[4];

    txbuf[0] = 0x9f;

    //    printf("Detect ROM chip\n");

    flash_do_cmd(txbuf, rxbuf, 4);

    //    printf("Flash jedec id %02X %02X %02X\n", rxbuf[1], rxbuf[2], rxbuf[3]);

    uint8_t mf = rxbuf[1];
    uint16_t id = (rxbuf[2] << 8) | rxbuf[3];

    used_flash_chip = NULL;
    for (int i = 0; i < sizeof(flash_chip) / sizeof(struct flash_chip); i++) {
        if (flash_chip[i].mf == mf && flash_chip[i].id == id) {
            vreg_set_voltage(flash_chip[i].voltage);
            if (!set_sys_clock_khz(flash_chip[i].sys_freq, true)) {
                printf("Can't set sys clock %dKHz\n", flash_chip[i].sys_freq);
                vreg_set_voltage(VREG_VOLTAGE_DEFAULT);
            }
            used_flash_chip = &flash_chip[i];
            break;
        }
    }
}

static void show_sysinfo(void)
{
    printf("ROM chip           : %s\n", used_flash_chip->name);
    printf("System frequency   : %d\n", clock_get_hz(clk_sys) / 1000);
    printf("ROM size           : %d MB\n", used_flash_chip->rom_size);
}

const struct flash_chip *get_flash_info(void)
{
    return used_flash_chip;
}

void n64_pi_restart(void)
{
    multicore_reset_core1();
    multicore_launch_core1(n64_pi);
}

int main(void)
{
    for (int i = 0; i <= 27; i++) {
        gpio_init(i);
        gpio_set_dir(i, GPIO_IN);
        gpio_set_pulls(i, false, false);
    }

    gpio_init(N64_CIC_DCLK);
    gpio_init(N64_CIC_DIO);
    gpio_init(N64_COLD_RESET);

    gpio_pull_up(N64_CIC_DIO);
    gpio_pull_up(N64_SI_DATA);

#ifndef N64CART_RP2040_PICO
    gpio_init(N64_SI_CLK);
    gpio_init(N64_SI_DATA);

    gpio_init(N64_NMI);

    gpio_init(N64_INT);
    gpio_pull_up(N64_INT);
    gpio_put(N64_INT, 1);
    gpio_set_dir(N64_INT, GPIO_OUT);
#endif

    setup_sysconfig();

    stdio_init_all();

#if defined(PICO_DEFAULT_LED_PIN)
#if PICO_LED_WS2812 == 1
    init_rgb_led();
#else
    gpio_init(PICO_DEFAULT_LED_PIN);
    gpio_set_dir(PICO_DEFAULT_LED_PIN, GPIO_OUT);
#endif
#endif

    //#ifdef DEBUG_INFO
    printf("N64cart fw v%d.%d (" GIT_HASH ") by pdaXrom!\n", FIRMWARE_VERSION / 256, FIRMWARE_VERSION % 256);
    //#endif

    if (used_flash_chip == NULL) {
        printf("Unknown ROM chip, system stopped!\n");
        while (true) {
            tight_loop_contents();
        }
    }
#ifdef DEBUG_INFO
    show_sysinfo();
#endif

    usbd_start();

    // disable XIP cache SRAM
    hw_clear_bits(&xip_ctrl_hw->ctrl, XIP_CTRL_EN_BITS);

    flash_quad_gpio_init();

    flash_quad_exit_cont_read_mode();
    flash_spi_mode();
    flash_config();

    uint32_t flash_map_size, flash_list_size;

    romfs_get_buffers_sizes(used_flash_chip->rom_size * 1024 * 1024, &flash_map_size, &flash_list_size);

    uint16_t *romfs_flash_map = (uint16_t *) pi_sram;
    uint8_t *romfs_flash_list = &pi_sram[flash_map_size];

    if (!romfs_start(get_romfs_start_offset(), used_flash_chip->rom_size * 1024 * 1024, romfs_flash_map,
                     romfs_flash_list)) {
        printf("Cannot start romfs!\n");
        while (true) {
            tight_loop_contents();
        }
    }

    romfs_file file;
    if (romfs_open_file("n64cart-manager.z64", &file, NULL) == ROMFS_NOERR) {
        romfs_read_map_table(pi_rom_lookup, 16384, &file);
        romfs_close_file(&file);

        backup_rom_lookup();
    } else {
        printf("romfs error: %s\n", romfs_strerror(file.err));
        while (true) {
            tight_loop_contents();
        }
    }

    flash_quad_cont_read_mode();

    multicore_launch_core1(n64_pi);

    si_main();
    cic_main();

    return 0;
}

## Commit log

2022-08-02 fixed wrong NMI and INT for cartridge schematic
2022-08-05 cartridge schematic
    [n64cart.brd, n64cart.sch]
2022-08-05 fixed for current hw
    [main.c]
2022-08-07 led port
2022-08-08 switch flash rom to lower and upper page
2022-08-10 fixed wrong byte order in sram
    [n64_pi.c]
2022-08-13 added capacitor to VBUS
    [n64cart.brd, n64cart.sch]
2022-09-10 fixed build test rom
    [main.c]
2022-09-10 latest version
    [n64cart.brd, n64cart.sch]
2022-09-10 cartrigde case
    [n64cart-back.stl, n64cart-front.stl, n64cart-misc.stl]
2022-09-11 schematic in pdf
    [n64cart.sch]
2022-10-04 added VID PID, thanks to https://pid.codes
2022-10-05 fixed usb info, added windows build for usb utility
    [dev_lowlevel.h]
2022-10-13 fixed macos usb enumeration error
    [dev_lowlevel.c]
2022-10-13 removed unnecessary comments, fixed headers
    [dev_lowlevel.c, main.c, n64_pi.c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]
2023-02-22 fixed find list entry, renamed get error string function
    [main.c]
2023-06-25 PI interrupts
2023-10-23 read flash in spi 4byte fast read mode
2023-10-24 use spi quad read (24bit address yet)
2023-10-24 flash fast quad read with EC (in SPI mode)
2023-10-25 initial spi/quad mode switcher, new usb utility for romfs
2023-10-25 fixed switching between spi and quad modes
    [flashrom.c, main.c]
2023-10-25 removed duplicate swap for 16 bit bus data
    [flashrom.c, main.c, n64_pi.c]
2023-11-01 usb romfs code optimization, reboot in bootloader option
    [dev_lowlevel.c, main.c]
2023-11-16 spi access to flash from N64
2023-11-17 fixed byte order in file attributes
    [main.c]
2023-11-17 usb reboot command, removed sram flash area - need to load it from romfs
    [dev_lowlevel.c, main.c, n64_pi.c]
2023-12-11 pi bus speed fix moved to usb file uploader
    [main.c, n64_pi.c]
2023-12-15 cic io implemented with gpio interrupts
2024-02-25 fixed array size, to prevent out of bounds when store the name and parameters of a save game file
    [n64_pi.c]
2024-03-12 rp2040 usb mapped into n64 pi space initial usb device driver for N64, ported from rp2040 fixed occasional spi flash reading errors (stuck bit) in high addresses
    [dev_lowlevel.c, dev_lowlevel.h, flashrom.c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]
2024-07-10 fix updated for new libdragon
    [main.c]
2024-07-15 cartridge flash 128MB
    [n64cart-1G.brd, n64cart-1G.sch]
2024-07-15 1Gbit flash schmatic and board
2024-07-30 moved to 128MB_cartridge branch
    [n64cart-1G.brd, n64cart-1G.sch]
2024-08-06 onboard rgb led support
2024-08-06 configuration for v1/v2 boards
2024-08-06 moved to board configuration
2024-08-11 1Gbit pdf schematic
    [n64cart-1G.brd, n64cart-1G.sch]
2024-08-11 schematics renamed by version and flash chip package
    [n64cart-v2-soic-8.brd, n64cart-v2-soic-8.sch, n64cart-v3-soic-16.brd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]
2024-08-13 fixed compatibility with single chip picocard (flash chip 16MB or less)
    [flashrom.c, main.c, n64_cic.c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]
2024-08-15 updated for pico sdk v2.0
2024-08-15 compatibility with pico sdk 1.5
2024-08-16 fixed schematic pdf v2
    [n64cart-v2-soic-8.sch]
2024-08-17 use led configuration from board config file
2024-08-17 uart disabled for pico-lite
2024-08-18 swap bytes for sram saves
    [main.c]
2024-10-27 moved uart log messages to syslog, boot screen statuses
2024-11-03 WCID compatible USB device
2024-11-05 fixed image viewer crash on big images
    [main.c]
2024-11-05 missed pull down resistor for V3
    [n64cart-v3-soic-16.brd, n64cart-v3-soic-16.sch]
2024-11-05 V3 updated
    [n64cart-v3-soic-16.brd]
2024-11-05 missed pulldown resistor for V2
    [n64cart-v2-soic-8.brd, n64cart-v2-soic-8.sch]
2024-11-13 fix don't save empty save file
    [main.c]
2025-01-21 usb type-c board with soic-16
    [n64cart-v3-soic-16-usbc.brd, n64cart-v3-soic-16-usbc.sch]
2025-03-15 fix flash ram vendor id
    [n64_pi.c]
2025-09-14 The following changes have been added to romfs: - show romfs free space - automatic tests for file system - prevent to use wrong read/write operation for opened/created file - reclaim list entry and 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
    [main.c]
2026-04-05 fix wrong mapping in flash ram emulation
    [main.c, n64_pi.c]
2026-06-06 add romfs-gui pt-br de and es translations
2026-06-13 fix USB ROMFS refresh display handling
    [dev_lowlevel.c, main.c]
2026-06-13 fix delay USB flash access until splash is visible
    [dev_lowlevel.c, main.c]
2026-06-13 fix keep USB splash active while commands are flowing
    [dev_lowlevel.c, main.c]
2026-09-07 fix ROMFS geometry and guard N64 flash writes
    [dev_lowlevel.c, main.c]
2026-09-08 validate ROMFS chains before file operations
2026-09-08 track ROMFS handle ownership and pending entries
2026-09-08 propagate ROMFS I/O errors and preserve partial writes
    [main.c]
2026-09-08 reuse chain positions within ROMFS writes

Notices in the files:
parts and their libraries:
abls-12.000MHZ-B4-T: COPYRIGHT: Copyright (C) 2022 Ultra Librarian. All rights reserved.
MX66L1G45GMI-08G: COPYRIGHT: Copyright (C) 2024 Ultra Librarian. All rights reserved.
